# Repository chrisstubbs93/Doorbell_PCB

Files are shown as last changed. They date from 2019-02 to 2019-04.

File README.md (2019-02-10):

# Lecturer Availability Door Announcer

## Abstract
Traditionally a student would have to summon a lecturer in a shared office by knocking on the door. This disturbs the other lecturers in the office, and the desired lecturer may not even be present.

A system to alert a specific lecturer to the presence of someone at the door is not currently widely adopted. To investigate how such a system should work, it is crucial to gain insight into the current solutions to the individual technical challenges.

## Introduction
The main aim of this project is to develop a battery-operated device with inputs to receive interaction from the student, and outputs to feed back to the student and lecturer. It is to be fixed to the inside of the door of a multiple occupied lecturer's room. Through this device anyone outside the door shall be able to raise the attention of a single lecturer, and not to everyone in the room (which is what knocking at the door does). When a student operates the device, a notification should be sent to the appropriate lecturer’s mobile phone. It should also be possible for students to see the status/availability of a lecturer from the device, which the lecturer can set.

## Hardware

 - ESP32-WROOM-32
 - Waveshare 2.9" B/W ePaper
 - TCA9548A i2c multiplexer
 - VCNL4020 IR proximity sensor(s)

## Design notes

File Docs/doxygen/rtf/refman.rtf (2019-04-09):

Lecturer Availability Door Announcer

AUTHOR
Version 1.1
Tue Apr 9 2019

Table of Contents

Table of contents

File Index
File List
Here is a list of all files with brief descriptions:
bitmaps.h pagenum
Config.ino pagenum
Doorbell.ino pagenum
GUI.ino pagenum
Hardware.ino pagenum
Settings.h pagenum
Settings_template.h pagenum
Web.ino pagenum

File Documentation
bitmaps.h File Reference
AAAAAAAAAAAAAAAAAAAAVariables
const unsigned char BmpLSBU [] PROGMEM

Detailed Description
Stores bitmap images for display in program memory

Variable Documentation
const unsigned char BmpLSBU [] PROGMEM
AAAAAAAAABAAAAAAAAABThe LSBU logo stored as an array.
Generated from http://javl.github.io/image2cpp/
Invert colours.
Definition at line 15 of file bitmaps.h.

Config.ino File Reference
AAAAAAAAACAAAAAAAAACFunctions
void initFS ()
bool loadConfig ()
bool saveConfig ()
String rot (String in)

Detailed Description
Handles SPIFFS filesystem, loading of configuration files, saving of configuration files.

Function Documentation
void initFS ()
AAAAAAAAADAAAAAAAAADTry to initialize the filesystem. Format the SPIFFS on error and try again (this is normal for first use).
Definition at line 7 of file Config.ino.
7 {
8 Serial.println("[INFO] Mounting filesystem...");
9 if (!SPIFFS.begin()) {
10 errorMsg("Failed to mount file sys.\nAttempting to format.\nThis is normal for 1st use.\nPlease wait 30 seconds.");
11 SPIFFS.format();
12 if (SPIFFS.begin()) {
13 Serial.println("[INFO] SPIFFS format complete");
14 } else {
15 return;
16 }
17 }
18 delay(10);
19 }
bool loadConfig ()
AAAAAAAAAEAAAAAAAAAETry to load the configuration JSON file contents into their variables.
Definition at line 22 of file Config.ino.
22 {
23 File configFile = SPIFFS.open("/config.json", "r");
24 if (!configFile) {
25 errorMsg("Failed to open config file");
26 settingMode = true;
27 return false;
28 }
29 size_t size = configFile.size();
30 if (size > 1024) {
31 errorMsg("Config file size is too large");
32 settingMode = true;
33 return false;
34 }
35 std::unique_ptr<char[]> buf(new char[size]); // Allocate a buffer to store contents of the file.
36 configFile.readBytes(buf.get(), size); //Mutable buffer
37 StaticJsonBuffer<5000> jsonBuffer;
38 JsonObject& json = jsonBuffer.parseObject(buf.get());
39 if (!json.success()) {
40 errorMsg("Failed to parse cfg file.\nThis is normal for 1st use.");
41 settingMode = true;
42 return false;
43 }
44 //Restore basic device settings
45 EAP_IDENTITY = (const char*)json["EAP_IDENTITY"];
46 EAP_PASSWORD = (const char*)json["EAP_PASSWORD"];
47 ssid = (const char*)json["ssid"];
48 wifipsk = (const char*)json["wifipsk"];
49 www_username = (const char*)json["www_username"];
50 www_password = (const char*)json["www_password"];
51 room = (const char*)json["room"];
52 thres = json["thres"];
53 busyNotif = json["busyNotif"];
54 powerSave = json["powerSave"];
55 sleepDelay = json["sleepDelay"];
56 if (sleepDelay < 1) sleepDelay = 1; //coerce to greater than zero
57
58 //Restore lecturer details
59 for (int i = 0; i < 5; i++) {
60 lecturerNames[i] = (const char*)json["lecturerNames"][(String)i];
61 lecturerIFTTkeys[i] = (const char*)json["lecturerIFTTkeys"][(String)i];
62 lecturerStatus[i] = (const char*)json["lecturerStatus"][(String)i];
63 }
64
65 //Serial.print("[INFO] Parameters loaded:");
66 //json.printTo(Serial);
67 //Serial.println();
68 return true;
69 }
String rot (String in)
AAAAAAAAAFAAAAAAAAAFROT13 encryption algorithm.
Definition at line 115 of file Config.ino.
115 {
116 String out;
117 for (int i = 0; i < in.length(); ++i) {
118 if (isalpha(in[i])) {
119 if (in[i] >= 'a' && in[i] <= 'm') {
120 out += char(in[i] + 13);
121 } else if (in[i] >= 'n' && in[i] <= 'z') {
122 out += char(in[i] - 13);
123 } else if (in[i] >= 'A' && in[i] <= 'M') {
124 out += char(in[i] + 13);
125 } else if (in[i] >= 'N' && in[i] <= 'Z') {
126 out += char(in[i] - 13);
127 }
128 } else {
129 out += char(in[i]);
130 }
131 }
132 return out;
133 }
bool saveConfig ()
AAAAAAAAAGAAAAAAAAAGSave the config variable to the configuration JSON file.
Definition at line 72 of file Config.ino.
72 {
73 StaticJsonBuffer<5000> jsonBuffer;
74 JsonObject& json = jsonBuffer.createObject();
75 //Store basic device settings
76 json["EAP_IDENTITY"] = EAP_IDENTITY;
77 json["EAP_PASSWORD"] = EAP_PASSWORD;
78 json["ssid"] = ssid;
79 json["wifipsk"] = wifipsk;
80 json["www_username"] = www_username;
81 json["www_password"] = www_password;
82 json["room"] = room;
83 json["thres"] = thres;
84 json["busyNotif"] = busyNotif;
85 json["powerSave"] = powerSave;
86 json["sleepDelay"] = sleepDelay;
87
88 //Store lecturer details
89 JsonObject& jsonLecNames = jsonBuffer.createObject();
90 JsonObject& jsonLecKeys = jsonBuffer.createObject();
91 JsonObject& jsonLecStatus = jsonBuffer.createObject();
92 for (int i = 0; i < 5; i++) {
93 jsonLecNames[(String)i] = lecturerNames[i];
94 jsonLecKeys[(String)i] = lecturerIFTTkeys[i];
95 jsonLecStatus[(String)i] = lecturerStatus[i];
96 }
97 json["lecturerNames"] = jsonLecNames;
98 json["lecturerIFTTkeys"] = jsonLecKeys;
99 json["lecturerStatus"] = jsonLecStatus;
100
101 //Serial.print("[INFO] Parameters stored:");
102 //json.printTo(Serial);
103 //Serial.println();
104
105 File configFile = SPIFFS.open("/config.json", "w");
106 if (!configFile) {
107 Serial.println("[ERROR] Failed to open config file for writing");
108 return false;
109 }
110 json.printTo(configFile);
111 return true;
112 }

Doorbell.ino File Reference
AAAAAAAAAHAAAAAAAAAHFunctions
GxIO_Class io (SPI, 15, 4, 5)
Define the hardware pins used by the ePaper display for SPI. 15=CS, 4=DC, 5=RST.

GxEPD_Class display (io, 5, 16)
Define the hardware pins used by the ePaper display for control. 5=RST, 16=BUSY..

WebServer webServer (80)
Web server used for setup wizard and config interface.

void setup ()
void loop ()
Variables
DNSServer dnsServer
DNS server used for captive portal in setup mode.

boolean settingMode
Is the device in setup wizard mode (true) or normal mode (false)?

int doorbells = 0
Number of VCNL4020 sensors detected.

bool sleeping = false
Is the device in or about to enter deep sleep mode for power saving?

Detailed Description
Main file for the Lecturer Availability Door Announcer final year BEng project by Chris Stubbs.

Function Documentation
GxEPD_Class display (io , 5 , 16 )
AAAAAAAAAIAAAAAAAAAI
Define the hardware pins used by the ePaper display for control. 5=RST, 16=BUSY..
GxIO_Class io (SPI , 15 , 4 , 5 )
AAAAAAAAAJAAAAAAAAAJ
Define the hardware pins used by the ePaper display for SPI. 15=CS, 4=DC, 5=RST.
void loop ()
AAAAAAAAAKAAAAAAAAAKLoop function runs continuously. Poll devices and run background tasks.
Definition at line 77 of file Doorbell.ino.
77 {
78 wifiTasks();
79 scanVCNLs();
80 checkButtons();
81 manageSleep();
82 delay(SCAN_INTERVAL);
83 }
void setup ()
AAAAAAAAALAAAAAAAAALSetup function runs once on startup. Detect boot mode (normal or waking up from deep sleep). Perform setup.
Definition at line 36 of file Doorbell.ino.
36 {
37 Wire.begin();
38 Serial.begin(115200);
39 Serial.println((String)"[INFO] Lecturer availability door announcer version " + (String)VERSION);
40 wakeup_reason();
41 display.init();
42 initGPIO();
43 if (bootmode() == 6) displayVersion();
44 initFS();
45 bool configstatus = loadConfig();
46 if (bootmode() == 3) { //wakeup cause by timer. Update battery % on screen and go back to sleep.
47 sleeping = true; //set the sleeping flag
48 writeNames(); //show the sleeping flag on screen
49 entersleep(); //go to sleep
50 }
51 if (configstatus) {
52 //Config loaded OK. Try to connect to WiFi.
53 if (connectWiFi()) {
54 //WiFi connected OK. Start config web server and continue boot.
55 startWebServer();
56 } else {
57 //WiFi failed to connect. Start setup mode and abort boot.
58 setupMode();
59 return;
60 }
61 }
62 else {
63 setupMode();
64 return; //abort boot to carry out initial setup wizard
65 }
66 detectVCNLs();
67 if (bootmode() == 1) {
68 int source = interruptSource();
69 Serial.println((String)"[INFO] Interrupt triggered by sensor " + interruptSource());
70 ring(source);
71 }
72 calibrateVCNLs();
73 writeNames();
74 }
WebServer webServer (80 )
AAAAAAAAAMAAAAAAAAAM
Web server used for setup wizard and config interface.

Variable Documentation
DNSServer dnsServer
AAAAAAAAANAAAAAAAAAN
DNS server used for captive portal in setup mode.
Definition at line 29 of file Doorbell.ino.
int doorbells = 0
AAAAAAAAAOAAAAAAAAAO
Number of VCNL4020 sensors detected.
Definition at line 32 of file Doorbell.ino.
boolean settingMode
AAAAAAAAAPAAAAAAAAAP
Is the device in setup wizard mode (true) or normal mode (false)?
Definition at line 31 of file Doorbell.ino.
bool sleeping = false
AAAAAAAAAQAAAAAAAAAQ
Is the device in or about to enter deep sleep mode for power saving?
Definition at line 33 of file Doorbell.ino.

GUI.ino File Reference
AAAAAAAAARAAAAAAAAARFunctions
void displayVersion ()
void errorMsg (String ermsg)
void setupMsg (String apSSID)
void writeNames ()
void addToLog (const String n)
void displayLog ()
void clearLog ()
void showInfo ()
String wordWrap (String in)
Variables
String logbuffer [8] = { "", "", "", "", "", "", "", "" }
Buffer of last 8 log messages to show on screen. FIFO queue.

const GFXfont * font = &FreeMonoBold9pt7b
Define the font used for the GUI.

Detailed Description
Handles drawing of GUI elements on ePaper display

Function Documentation
void addToLog (const String n)
AAAAAAAAASAAAAAAAAASShuffle the log buffer and add a new time. Display log.
Definition at line 115 of file GUI.ino.
116 {
117 for (int i = 0; i < 7; i++) {
118 logbuffer[i] = logbuffer[i + 1];
119 }
120 logbuffer[7] = n;
121 displayLog();
122 }
void clearLog ()
AAAAAAAAATAAAAAAAAATRemove all entries in the log buffer.
Definition at line 139 of file GUI.ino.
140 {
141 for (int i = 0; i <= 7; i++) {
142 logbuffer[i] = "";
143 }
144 }
void displayLog ()
AAAAAAAAAUAAAAAAAAAUDisplay all log items in the buffer, most recent at the bottom.
Definition at line 125 of file GUI.ino.
126 {
127 display.setRotation(1);
128 display.fillScreen(GxEPD_WHITE);
129 display.setTextColor(GxEPD_BLACK);
130 display.setFont(font);
131 display.setCursor(0, 0);
132 for (int i = 0; i < 8; i++) {
133 display.println(logbuffer[i]);
134 }
135 display.update();
136 }
void displayVersion ()
AAAAAAAAAVAAAAAAAAAVDisplays an LSBU splashscreen followed by a description/version no. splashscreen.
Definition at line 11 of file GUI.ino.
12 {
13 //set up parameters
14 display.setRotation(1);
15 display.fillScreen(GxEPD_WHITE);
16 display.setTextColor(GxEPD_BLACK);
17 display.setFont(font);
18 //show LSBU logo
19 display.drawBitmap(0, 0, BmpLSBU, 296, 128, GxEPD_BLACK);
20 display.update();
21 delay(2000);
22 //Show version
23 display.fillScreen(GxEPD_WHITE);
24 display.setCursor(0, 0);
25 display.println();
26 display.println("Lecturer availability door");
27 display.println("announcer");
28 display.println();
29 display.println("Final year BEng project");
30 display.println("By Chris Stubbs 2018/19");
31 display.println((String)"FW Revision: " + (String)VERSION);
32 display.println("Starting up...");
33 display.update();
34 delay(3000);
35 }
void errorMsg (String ermsg)
AAAAAAAAAWAAAAAAAAAWDisplays a full screen error message with title and content for 5 seconds. Can be dismissed by pressing either button. Message is also printed to the serial port and the ERROR LED flashed.
Definition at line 38 of file GUI.ino.
39 {
40 digitalWrite(LEDERRPIN, HIGH);
41 String tmpermsg = ermsg;
42 tmpermsg.replace("\n", " ");
43 Serial.println("[ERROR] " + tmpermsg);
44 display.setRotation(1);
45 display.fillScreen(GxEPD_WHITE);
46 display.setTextColor(GxEPD_BLACK);
47 display.setFont(font);
48 display.setCursor(0, 0);
49 display.println();
50 display.println("!!!----!!! Error !!!----!!!");
51 display.println(ermsg);
52 display.update();
53 unsigned long tmr = millis();
54 while ((millis() - tmr < 5000)) {
55 if (digitalRead(BTNAPIN)) break; //allow button press to dismiss error
56 if (digitalRead(BTNBPIN)) break;
57 }
58 digitalWrite(LEDERRPIN, LOW);
59 }
void setupMsg (String apSSID)
AAAAAAAAAXAAAAAAAAAXInstructs user to connect to access point and run setup wizard.
Definition at line 62 of file GUI.ino.
63 {
64 Serial.println((String)"[INFO] Starting config access point named " + apSSID);
65 Serial.println((String)"[INFO] Starting config web server at " + WiFi.softAPIP().toString());
66 display.setRotation(1);
67 display.fillScreen(GxEPD_WHITE);
68 display.setTextColor(GxEPD_BLACK);
69 display.setFont(font);
70 display.setCursor(0, 14);
71 display.println("------- Config Mode -------");
72 display.println("Scan for access points");
73 display.println("and connect to " + apSSID + ".");
74 display.println();
75 display.println("Go to " + WiFi.softAPIP().toString());
76 display.println("to set up.");
77 display.update();
78 }
void showInfo ()
AAAAAAAAAYAAAAAAAAAYShows simple menu with FW version, IP, n sensors found. Also allows user to initiate a reset of the device configuration.
Definition at line 147 of file GUI.ino.
147 {
148 //set up parameters
149 bool shown = false;
150 while (!shown) {
151 display.setRotation(1);
152 display.fillScreen(GxEPD_WHITE);
153 display.setTextColor(GxEPD_BLACK);
154 display.setFont(font);
155 display.fillScreen(GxEPD_WHITE);
156 display.setCursor(0, 14);
157 display.println((String)"FW Revision: " + (String)VERSION);
158 display.println("IP addr: " + WiFi.localIP().toString());
159 display.println("Connected to " + ssid);
160 display.println((String)doorbells + " sensors found");
161 display.println();
162 display.println();
163 display.println("[A]-Close [B]-Reset");
164 display.update();
165 shown = true;
166 while (digitalRead(BTNAPIN)) {}
167 unsigned long tmr = millis();
168 while ((millis() - tmr < 60000)) {
169 wifiTasks();//Run WiFi background tasks while waiting
170 if (digitalRead(BTNAPIN)) break;
171 if (digitalRead(BTNBPIN)) {
172 while (digitalRead(BTNBPIN)) {}
173 display.fillScreen(GxEPD_WHITE);
174 Serial.println("Are you sure you want to\nreset this device?");
175 display.setCursor(0, 14);
176 display.println("Are you sure you want to");
177 display.println("reset this device?");
178 display.println();
179 display.println("All settings will be lost.");
180 display.println();
181 display.println("[A]-No");
182 display.println("[B]-Yes (hold for 5 sec)");
183 display.update();
184 if (digitalRead(BTNAPIN)) break;
185 while (1) {
186 if (digitalRead(BTNAPIN)) {
187 shown = false;
188 break;
189 }
190 if (digitalRead(BTNBPIN)) {
191 unsigned long tmr2 = millis();
192 while (digitalRead(BTNBPIN)) {
193 if ((millis() - tmr2 > 5000)) {
194 //Clear settings and restart
195 SPIFFS.remove("/config.json");
196 delay(1000);
197 ESP.restart();
198 }
199 }
200 }
201 }
202 }
203 }
204 }
205 writeNames();
206 }
String wordWrap (String in)
AAAAAAAAAZAAAAAAAAAZWrap words around spaces to print nicely on screen.
Definition at line 209 of file GUI.ino.
209 {
210 if (in.length() > 27) {
211 for (int i = 27; i > 1; i--) { //work backwards from limit of string to first space
212 if (in.charAt(i) == ' ') {
213 return (in.substring(0, i) + "\n" + in.substring(i + 1, in.length())); //there is a space to replace with a line break
214 }
215 }
216 return in; //There were no spaces to replace, return plain string
217 } else {
218 return in; //String will fit on screen, return plain string
219 }
220 }
void writeNames ()
AAAAAAAABAAAAAAAAABAWrite the room name, all lecturer names, status, battery percentage and sleep status to the display.
Definition at line 81 of file GUI.ino.
82 {
83 display.setRotation(1);
84 display.fillScreen(GxEPD_WHITE);
85 display.setTextColor(GxEPD_BLACK);
86 display.setFont(font);
87 display.setCursor(0, 14);
88 display.println("-------- Room " + room + " --------");
89 for (int i = 0; i < 5; i++) {
90 display.setCursor(0, 35 + (16 * i));
91 display.println(lecturerNames[i]);
92 display.setCursor(175, 35 + (16 * i));
93 if (lecturerNames[i] != "") display.println("-");
94 display.setCursor(190, 35 + (16 * i));
95 display.println(lecturerStatus[i]);
96 }
97 display.setCursor(270, 122);
98 if (sleeping) display.println("Zz");
99
100 //Draw battery icon and percentage
101 float VBAT = ((200.0f / 100.0f) * 3.30f * float(analogRead(BATTMONPIN)) / 4095.0f) + 0.2f; // LiPo battery
102 int vbatt = (float)((100.0f / 4.2f) * VBAT);
103 Serial.print("[INFO] Battery Voltage = "); Serial.print(VBAT, 2); Serial.println(" V");
104 display.drawRect(1, 113, 30, 13, GxEPD_BLACK);
105 display.drawRect(2, 114, 28, 11, GxEPD_BLACK);
106 display.fillRect(31, 116, 3, 7, GxEPD_BLACK);
107 display.fillRect(1, 113, (int)(vbatt / 3.33), 13, GxEPD_BLACK); //fill to battery %
108 display.setCursor(35, 123);
109 display.println((String)vbatt + "%");
110
111 display.update(); //Send buffer to display
112 }

Variable Documentation
const GFXfont* font = &FreeMonoBold9pt7b
AAAAAAAABBAAAAAAAABB
Define the font used for the GUI.
Definition at line 8 of file GUI.ino.
String logbuffer[8] = { "", "", "", "", "", "", "", "" }
AAAAAAAABCAAAAAAAABC
Buffer of last 8 log messages to show on screen. FIFO queue.
Definition at line 7 of file GUI.ino.

Hardware.ino File Reference
AAAAAAAABDAAAAAAAABDFunctions
void initGPIO ()
void setVCOM (unsigned char d)
void tcaselect (uint8_t i)
int tcaget ()
void detectVCNLs ()
void calibrateVCNLs ()
void checkButtons ()
void manageSleep ()
void entersleep ()
void wakeup_reason ()
int bootmode ()
void scanVCNLs ()
void setupVCNLinterrupt ()
uint16_t getBackgroundProximity ()
int interruptSource ()
Variables
long average [] = {0, 0, 0, 0, 0, 0, 0, 0}
Array of average reading of all sensors.

long threshold [] = {0, 0, 0, 0, 0, 0, 0, 0}
Array of threshold limits to trigger each sensor.

long reading [] = {0, 0, 0, 0, 0, 0, 0, 0}
Current reading of each sensor.

Adafruit_VCNL4010 vcnl
Object for the VNCL sensor.

unsigned long lastPressed = 0
Time in ms since boot that a sensor was last pressed. Used to determine when to enter sleep mode after inactivity.

Detailed Description
Handles I2C multiplexer, connection to VCNL IR proximity sensors, proximity sensor related functions, initialisation of GPIO, scanning of buttons.

Function Documentation
int bootmode ()
AAAAAAAABEAAAAAAAABEDetermine type of boot mode. 1 = sensor interrupt, 2 = button interrupt, 3 = periodic timer wakeup, 6 = normal startup.
Definition at line 168 of file Hardware.ino.
168 {
169 esp_sleep_wakeup_cause_t wakeup_reason;
170 wakeup_reason = esp_sleep_get_wakeup_cause();
171 if (wakeup_reason > 5 or wakeup_reason < 1){
172 return 6;
173 } else {
174 return wakeup_reason;
175 }
176 }
void calibrateVCNLs ()
AAAAAAAABFAAAAAAAABFCalibrate VCNL threshold by averaging N_THRES_SAMPLES samples and multiplying by thres
Definition at line 94 of file Hardware.ino.
94 {
95 for (int bus = 0; bus < doorbells; bus++) {
96 tcaselect(bus);
97 Serial.print("[INFO] Calibrating proximity threshold on bus " + (String)bus + " ");
98 vcnl.setLEDcurrent(LEDCURR); //Set IR LED on to take measurement
99 delay(10); //small delay to allow IR LED to stabilise
100 for (int i = 0; i <= N_THRES_SAMPLES; i++) {
101 int tmp = vcnl.readProximity();
102 average[bus] = average[bus] + tmp;
103 Serial.print((String)((100 / N_THRES_SAMPLES)*i) + "% ");
104 delay(100);
105 }
106 vcnl.setLEDcurrent(0); //Set IR LED off
107 average[bus] = average[bus] / N_THRES_SAMPLES;
108 threshold[bus] = average[bus] * thres;
109 Serial.println((String)"Average level was: " + average[bus] + " Threshold set to: " + threshold[bus]);
110 }
111 Serial.println("[INFO] Calibration done");
112 }
void checkButtons ()
AAAAAAAABGAAAAAAAABGCheck if hardware buttons are pressed and run actions.
Definition at line 115 of file Hardware.ino.
115 {
116 if (digitalRead(BTNAPIN)) {
117 lastPressed = millis(); //record the button was pressed for sleep mode
118 Serial.println("[INFO] Button A Pressed");
119 showInfo();
120 while (digitalRead(BTNAPIN)) {}
121 }
122 if (digitalRead(BTNBPIN)) {
123 lastPressed = millis(); //record the button was pressed for sleep mode
124 Serial.println("[INFO] Button B Pressed");
125 while (digitalRead(BTNBPIN)) {}
126 }
127 }
void detectVCNLs ()
AAAAAAAABHAAAAAAAABHAttempt to initialise connected VCNL's one by one
Definition at line 64 of file Hardware.ino.
64 {
65 Serial.println("[INFO] Autodetecting sensors....");
66 //addToLog("Autodetecting sensors....");
67 for (int bus = 0; bus <= 7; bus++) {
68 tcaselect(bus);
69 int trynum = 1;
70 while (! vcnl.begin() && trynum < TRIES) {
71 if (DEBUG_READINGS == 1) Serial.println((String)"[DEBUG] Try " + trynum);
72 trynum++;
73 delay(100);
74 }
75 if (trynum < TRIES) {
76 //found
77 Serial.println((String)"[INFO] Found VCNL40xx on bus " + bus);
78 doorbells++;
79 }
80 else {
81 //not found
82 Serial.println((String)"[INFO] No VCNL40xx on bus " + (String)bus + " terminating autodetection.");
83 break;
84 }
85 }
86 Serial.println("[INFO] Number of doorbells found: " + (String)doorbells);
87 //addToLog((String)doorbells + " sensors found.");
88 if (doorbells == 0) {
89 errorMsg("Hardware error.\nNo VCNL sesnors found.\nContact support.");
90 }
91 }
void entersleep ()
AAAAAAAABIAAAAAAAABISet up interrupts to wake device, then go to deep sleep for power saving.
Definition at line 143 of file Hardware.ino.
143 {
144 Serial.println("[INFO] Entering sleep mode");
145 esp_sleep_enable_ext0_wakeup(GPIO_NUM_32, 0); //interrupt on VCNL sum
146 esp_sleep_enable_ext1_wakeup(INTERRUPTPINMASK, ESP_EXT1_WAKEUP_ANY_HIGH); //interrupt on A/B buttons
147 esp_sleep_enable_timer_wakeup(1800 * 1000000); //interrupt every hour to update battery etc
148 delay(500); //delay to finish setup before CPU halted
149 esp_deep_sleep_start();
150 }
uint16_t getBackgroundProximity ()
AAAAAAAABJAAAAAAAABJTake a proximity reading without disturbing the interrupt setup.
Definition at line 235 of file Hardware.ino.
235 {
236 vcnl.setLEDcurrent(LEDCURR); //Set IR LED on to take measurement
237 delay(10); //small delay to allow IR LED to stabilise
238 vcnl.write8(0x80, 0x03); //run continuous measurements
239 uint16_t p = vcnl.read8(0x87);
240 p = p << 8;
241 p = p + vcnl.read8(0x88);
242 return p;
243 }
void initGPIO ()
AAAAAAAABKAAAAAAAABKInitialise the GPIO pins. This should be run AFTER initialising the display so the MISO pin can be detached from the pin matrix and reused.
Definition at line 17 of file Hardware.ino.
17 {
18 pinMode(BTNAPIN, INPUT);
19 pinMode(BTNBPIN, INPUT);
20 pinMode(INTERRUPTPIN, INPUT);
21 pinMode(BATTMONPIN, INPUT);
22
23 pinMatrixInDetach(VSPIQ_OUT_IDX, false, false); //detatch pin 19 from the VSPI MISO.
24 pinMode(LEDAVAILPIN, OUTPUT);
25 pinMode(LEDBUSYPIN, OUTPUT);
26 pinMode(LEDOKPIN, OUTPUT);
27 pinMode(LEDERRPIN, OUTPUT);
28 }
int interruptSource ()
AAAAAAAABLAAAAAAAABLDetermine which sensor caused a hardware interrupt.
Definition at line 246 of file Hardware.ino.
246 {
247 for (int bus = 0; bus < doorbells; bus++) {
248 tcaselect(bus);
249 //Serial.print((String)"Device " + bus + " has an interrupt register with contents "); Serial.println(vcnl.read8(0x8E),HEX);
250 if (vcnl.read8(0x8E) & 0x01) { //check interrupt register on VCNL
251 return bus;
252 }
253 }
254 return 0;
255 }
void manageSleep ()
AAAAAAAABMAAAAAAAABMDetermine if device should enter deep sleep for power saving.
Definition at line 130 of file Hardware.ino.
130 {
131 if (powerSave) {
132 if (millis() - lastPressed > sleepDelay * 60000) {
133 //go to sleep if no activity for x mins
134 setupVCNLinterrupt(); //set up the VCNLs for interrupt
135 sleeping = true; //set the sleeping flag
136 writeNames(); //show the sleeping flag on screen
137 entersleep(); //go to sleep
138 }
139 }
140 }
void scanVCNLs ()
AAAAAAAABNAAAAAAAABNTake reading from each sensor. Notify lecturer if above threshold.
Definition at line 179 of file Hardware.ino.
179 {
180 if (settingMode) return;
181 for (int bus = 0; bus < doorbells; bus++) {
182 tcaselect(bus);
183 vcnl.setLEDcurrent(LEDCURR); //Set IR LED on to take measurement
184 delay(10); //small delay to allow IR LED to stabilise
185 reading[bus] = vcnl.readProximity();
186 if (reading[bus] > threshold[bus]) {
187 Serial.println((String)"[INFO] Doorbell pressed on bus " + bus + " reading:" + reading[bus]);
188 ring(bus);
189 while (reading[bus] > threshold[bus])
190 {
191 reading[bus] = vcnl.readProximity();
192 delay(SCAN_INTERVAL);
193 }
194 }
195 //Set LED off to save power
196 vcnl.setLEDcurrent(0);
197 }
198 if (DEBUG_READINGS == 1) {
199 Serial.print("[DEBUG] Current readings:,");
200 for (int i = 0; i <= 7; i++) {
201 char buf[50];
202 sprintf(buf, "%05d,", reading[i]);
203 Serial.print(buf);
204 }
205 Serial.print("[DEBUG] Thresholds: ,");
206 for (int i = 0; i <= 7; i++) {
207 char buf[50];
208 sprintf(buf, "%05d,", threshold[i]);
209 Serial.print(buf);
210 }
211 }
212 }
void setupVCNLinterrupt ()
AAAAAAAABOAAAAAAAABOSet up interrupt on each device when threshold exceeded. (allows detection of touch interaction when CPU asleep).
Definition at line 215 of file Hardware.ino.
215 {
216 //once the interrupt is set up, the proximity must only be read using background measurement
217 for (int bus = 0; bus < doorbells; bus++) {
218 tcaselect(bus);
219 Serial.println("[INFO] Setting interrupt on bus " + (String)bus + " ");
220 vcnl.setLEDcurrent(LEDCURR); //Set IR LED on to take measurement
221 delay(10); //small delay to allow IR LED to stabilise
222 vcnl.write8(0x89, 0x02); //set up interrupt type
223 //set low thres to 0
224 vcnl.write8(0x8A, 0x00);
225 vcnl.write8(0x8B, 0x00);
226 //set high thres to value from array
227 vcnl.write8(0x8C, highByte(threshold[bus]));
228 vcnl.write8(0x8D, lowByte(threshold[bus]));
229 //run continuous measurements
230 vcnl.write8(0x80, 0x03);
231 }
232 }
void setVCOM (unsigned char d)
AAAAAAAABPAAAAAAAABPSet the VCOM. This isn't normally needed unless the ePaper is particularly bad.
Definition at line 31 of file Hardware.ino.
31 {
32 digitalWrite(4, LOW);
33 digitalWrite(15, LOW);
34 SPI.transfer(0x2C); //Write VCOM register
35 digitalWrite(15, HIGH);
36 digitalWrite(4, HIGH);
37 digitalWrite(15, LOW);
38 SPI.transfer(d);
39 digitalWrite(15, HIGH);
40 }
int tcaget ()
AAAAAAAABQAAAAAAAABQCheck the current i2c sub-bus for a specific sensor. Output 0...7
Definition at line 54 of file Hardware.ino.
54 {
55 Wire.requestFrom(TCAADDR, 1);
56 byte c = Wire.read();
57 for (int i = 0; i <= 7; i++) {
58 if (c == 0x01) return i;
59 c = c >> 1;
60 }
61 }
void tcaselect (uint8_t i)
AAAAAAAABRAAAAAAAABRSelects which i2c sub-bus on the mux for a specific sensor to connect to and checks it, retrying if it's not correct. (input 0...7)
Definition at line 43 of file Hardware.ino.
43 {
44 if (i > 7) return;
45 do {
46 if (DEBUG_READINGS == 1) Serial.println((String)"[DEBUG] Selecting bus " + i);
47 Wire.beginTransmission(TCAADDR);
48 Wire.write(1 << i);
49 Wire.endTransmission();
50 } while (!(tcaget() == i));
51 }
void wakeup_reason ()
AAAAAAAABSAAAAAAAABSPrint the reason for wakeup to the serial port.
Definition at line 153 of file Hardware.ino.
153 {
154 esp_sleep_wakeup_cause_t wakeup_reason;
155 wakeup_reason = esp_sleep_get_wakeup_cause();
156 switch (wakeup_reason)
157 {
158 case 1 : Serial.println("[INFO] Wakeup caused by external signal using RTC_IO"); break; //EXT0 - VCNL
159 case 2 : Serial.println("[INFO] Wakeup caused by external signal using RTC_CNTL"); break; //EXT1 - A/B
160 case 3 : Serial.println("[INFO] Wakeup caused by timer"); break;
161 case 4 : Serial.println("[INFO] Wakeup caused by touchpad"); break;
162 case 5 : Serial.println("[INFO] Wakeup caused by ULP program"); break;
163 default : Serial.println("[INFO] Wakeup was not caused by deep sleep"); break;
164 }
165 }

Variable Documentation
long average[] = {0, 0, 0, 0, 0, 0, 0, 0}
AAAAAAAABTAAAAAAAABT
Array of average reading of all sensors.
Definition at line 7 of file Hardware.ino.
unsigned long lastPressed = 0
AAAAAAAABUAAAAAAAABU
Time in ms since boot that a sensor was last pressed. Used to determine when to enter sleep mode after inactivity.
Definition at line 14 of file Hardware.ino.
long reading[] = {0, 0, 0, 0, 0, 0, 0, 0}
AAAAAAAABVAAAAAAAABV
Current reading of each sensor.
Definition at line 9 of file Hardware.ino.
long threshold[] = {0, 0, 0, 0, 0, 0, 0, 0}
AAAAAAAABWAAAAAAAABW
Array of threshold limits to trigger each sensor.
Definition at line 8 of file Hardware.ino.
Adafruit_VCNL4010 vcnl
AAAAAAAABXAAAAAAAABX
Object for the VNCL sensor.
Definition at line 11 of file Hardware.ino.

Settings.h File Reference
AAAAAAAABYAAAAAAAABYVariables
String ssid = ""
String wifipsk = ""
String EAP_IDENTITY = ""
String EAP_PASSWORD = ""
String www_username = "admin"
String www_password = "esp32"
String room = "T815"
String lecturerNames [5] = { "Chris Stubbs", "Oswaldo Cadenas", "Fang Duan", "Jeremy Ball", ""}
String lecturerIFTTkeys [5] = { "cWn7UxwOXLX-pqSYsF82Ge", "REMOVEcMalAefCTKzVtoXHlMz9Wk", "", "", ""}
String lecturerStatus [5] = { "Available", "Away", "Busy", "Busy", ""}
float thres = 2
bool busyNotif = false
bool powerSave = false
int sleepDelay = 1

Detailed Description
Contains user settings and presets that can be changed for build

Variable Documentation
bool busyNotif = false
AAAAAAAABZAAAAAAAABZ
Definition at line 20 of file Settings.h.
String EAP_IDENTITY = ""
AAAAAAAACAAAAAAAAACA
Definition at line 9 of file Settings.h.
String EAP_PASSWORD = ""
AAAAAAAACBAAAAAAAACB
Definition at line 10 of file Settings.h.
String lecturerIFTTkeys[5] = { "cWn7UxwOXLX-pqSYsF82Ge", "REMOVEcMalAefCTKzVtoXHlMz9Wk", "", "", ""}
AAAAAAAACCAAAAAAAACC
Definition at line 17 of file Settings.h.
String lecturerNames[5] = { "Chris Stubbs", "Oswaldo Cadenas", "Fang Duan", "Jeremy Ball", ""}
AAAAAAAACDAAAAAAAACD
Definition at line 16 of file Settings.h.
String lecturerStatus[5] = { "Available", "Away", "Busy", "Busy", ""}
AAAAAAAACEAAAAAAAACE
Definition at line 18 of file Settings.h.
bool powerSave = false
AAAAAAAACFAAAAAAAACF
Definition at line 21 of file Settings.h.
String room = "T815"
AAAAAAAACGAAAAAAAACG
Definition at line 15 of file Settings.h.
int sleepDelay = 1
AAAAAAAACHAAAAAAAACH
Definition at line 22 of file Settings.h.
String ssid = ""
AAAAAAAACIAAAAAAAACI
Definition at line 7 of file Settings.h.
float thres = 2
AAAAAAAACJAAAAAAAACJ
Definition at line 19 of file Settings.h.
String wifipsk = ""
AAAAAAAACKAAAAAAAACK
Definition at line 8 of file Settings.h.
String www_password = "esp32"
AAAAAAAACLAAAAAAAACL
Definition at line 12 of file Settings.h.
String www_username = "admin"
AAAAAAAACMAAAAAAAACM
Definition at line 11 of file Settings.h.

Settings_template.h File Reference
AAAAAAAACNAAAAAAAACNVariables
String ssid = ""
WiFi SSID the device will connect to. Set from setup wizard.

String wifipsk = ""
WiFi pre-shared key (password) the device will connect with. Set from setup wizard.

String EAP_IDENTITY = ""
WPA2-ENTERPRISE (eduroam) email address. Set from setup wizard.

String EAP_PASSWORD = ""
WPA2-ENTERPRISE (eduroam) password. Set from setup wizard.

String www_username = "admin"
Defualt username for web config interface. Set from web config interface.

String www_password = "esp32"
Defualt password for web config interface. Set from web config interface.

String room = "T815"
Name of room device is fixed to. Set from web config interface.

String lecturerNames [5] = { "Name1", "Name2", "Name3", "", ""}
Array of lectureres names. Set from web config interface.

String lecturerIFTTkeys [5] = { "Key1", "Key2", "Key3", "", ""}
Array of lecturer IFTTT keys. Set from web config interface.

String lecturerStatus [5] = { "Available", "Away", "Busy", "", ""}
Array of lecturer status. Set from web config interface.

float thres = 2
Threshold for sensor.

bool busyNotif = false
Notify lecturer anyway if they are busy?

bool powerSave = false
Enter power saving mode after inactivity?

int sleepDelay = 15
Period of inactivity in mins before entering power save mode.

Detailed Description
Contains user settings and presets that can be changed for build. Rename this file to Settings.h.

Variable Documentation
bool busyNotif = false
AAAAAAAACOAAAAAAAACO
Notify lecturer anyway if they are busy?
Definition at line 20 of file Settings_template.h.
String EAP_IDENTITY = ""
AAAAAAAACPAAAAAAAACP
WPA2-ENTERPRISE (eduroam) email address. Set from setup wizard.
Definition at line 9 of file Settings_template.h.
String EAP_PASSWORD = ""
AAAAAAAACQAAAAAAAACQ
WPA2-ENTERPRISE (eduroam) password. Set from setup wizard.
Definition at line 10 of file Settings_template.h.
String lecturerIFTTkeys[5] = { "Key1", "Key2", "Key3", "", ""}
AAAAAAAACRAAAAAAAACR
Array of lecturer IFTTT keys. Set from web config interface.
Definition at line 17 of file Settings_template.h.
String lecturerNames[5] = { "Name1", "Name2", "Name3", "", ""}
AAAAAAAACSAAAAAAAACS
Array of lectureres names. Set from web config interface.
Definition at line 16 of file Settings_template.h.
String lecturerStatus[5] = { "Available", "Away", "Busy", "", ""}
AAAAAAAACTAAAAAAAACT
Array of lecturer status. Set from web config interface.
Definition at line 18 of file Settings_template.h.
bool powerSave = false
AAAAAAAACUAAAAAAAACU
Enter power saving mode after inactivity?
Definition at line 21 of file Settings_template.h.
String room = "T815"
AAAAAAAACVAAAAAAAACV
Name of room device is fixed to. Set from web config interface.
Definition at line 15 of file Settings_template.h.
int sleepDelay = 15
AAAAAAAACWAAAAAAAACW
Period of inactivity in mins before entering power save mode.
Definition at line 22 of file Settings_template.h.
String ssid = ""
AAAAAAAACXAAAAAAAACX
WiFi SSID the device will connect to. Set from setup wizard.
Definition at line 7 of file Settings_template.h.
float thres = 2
AAAAAAAACYAAAAAAAACY
Threshold for sensor.
Definition at line 19 of file Settings_template.h.
String wifipsk = ""
AAAAAAAACZAAAAAAAACZ
WiFi pre-shared key (password) the device will connect with. Set from setup wizard.
Definition at line 8 of file Settings_template.h.
String www_password = "esp32"
AAAAAAAADAAAAAAAAADA
Defualt password for web config interface. Set from web config interface.
Definition at line 12 of file Settings_template.h.
String www_username = "admin"
AAAAAAAADBAAAAAAAADB
Defualt username for web config interface. Set from web config interface.
Definition at line 11 of file Settings_template.h.

Web.ino File Reference
AAAAAAAADCAAAAAAAADCFunctions
const IPAddress apIP (192, 168, 1, 1)
Fixed IP address of device for setup wizard in AP mode.

void wifiTasks ()
void ring (const int bus)
boolean connectWiFi ()
boolean checkConnection ()
void startWebServer ()
void setupMode ()
String makePage (String title, String contents)
String urlDecode (String input)
void handleRoot ()
String generateStatusDropdown (uint8_t n)
void saveSettings ()
void handleNotFound ()
void handleReset ()
void handleSetupRoot ()
void handleSettings ()
void handleEduroam ()
void handleSetAP ()
Variables
const char * apSSID = "_SETUP"
Name of SSID for setup wizard access point.

String ssidList
List of all detected SSIDs from scan.

Detailed Description
Handles WiFi access point, WiFi client, DNS server, webservers for initial setup wizard and configuration, IFTTT integration. Also contains all HTML for webservers

Function Documentation
const IPAddress apIP (192 , 168 , 1 , 1 )
AAAAAAAADDAAAAAAAADD
Fixed IP address of device for setup wizard in AP mode.
boolean checkConnection ()
AAAAAAAADEAAAAAAAADECheck WiFi is connected.
Definition at line 158 of file Web.ino.
158 {
159 int count = 0;
160 while ( count < 15 ) {
161 if (WiFi.status() == WL_CONNECTED) {
162 Serial.println("\n[INFO] Connected!");
163 settingMode = false;
164 return (true);
165 }
166 delay(500);
167 Serial.print(".");
168 count++;
169 }
170 Serial.println();
171 return false;
172 }
boolean connectWiFi ()
AAAAAAAADFAAAAAAAADFAttempt to connect to specified WiFi SSID. After 3 failures, default to setup wizard.
Definition at line 103 of file Web.ino.
103 {
104 int connAttempts = 0;
105 while (connAttempts < 3) {
106 connAttempts++;
107 if (EAP_IDENTITY == "") {
108 //if wpa2-psk is configured
109 Serial.println((String)"[INFO] WPA2-PSK mode.");
110 WiFi.begin(ssid.c_str(), rot(wifipsk).c_str());
111 } else {
112 //if eduroam is configured
113 Serial.println((String)"[INFO] WPA2-Enterprise mode.");
114 WiFi.disconnect(true);
115 WiFi.mode(WIFI_STA);
116 const unsigned char* EAP_IDENTITY_A = reinterpret_cast<const unsigned char *>( rot(EAP_IDENTITY).c_str() ); //convert strings to unsigned char for enterprise functions
117 const unsigned char* EAP_PASSWORD_A = reinterpret_cast<const unsigned char *>( rot(EAP_PASSWORD).c_str() );
118 esp_wifi_sta_wpa2_ent_set_username(EAP_IDENTITY_A, strlen(rot(EAP_IDENTITY).c_str())); //set enterprise wifi parameters
119 esp_wifi_sta_wpa2_ent_set_password(EAP_PASSWORD_A, strlen(rot(EAP_PASSWORD).c_str()));
120 esp_wpa2_config_t config = WPA2_CONFIG_INIT_DEFAULT(); //set config settings to default
121 esp_wifi_sta_wpa2_ent_enable(&config); //enable enterprise mode
122 WiFi.begin(ssid.c_str(), rot(wifipsk).c_str()); //connect to AP
123 }
124 Serial.print("[INFO] Connecting to " + ssid + ". Attempt " + connAttempts);
125 addToLog(ssid + " connecting");
126 if (checkConnection()) {
127 return true; //Connected OK.
128 } else {
129 //Connection failed. Try again.
130 if (connAttempts == 3) {
131 //Display last attempt error
132 errorMsg("WiFi connection timed out.\nThis is attempt " + (String)connAttempts + "/3.\nAborting connection.\nEntering setup mode.");
133 } else {
134 //Display retry error
135 errorMsg("WiFi connection timed out.\nThis is attempt " + (String)connAttempts + "/3.\nTrying again in 10s.\nPress [A] to retry now.\nPress [B] to run setup.");
136 unsigned long tmr = millis();
137 while ((millis() - tmr < 10000)) {
138 if (digitalRead(BTNAPIN)) {
139 //User requested retry
140 if (connAttempts == 3) connAttempts = 2; //Manually allow one more try if on last try.
141 break;
142 }
143 if (digitalRead(BTNBPIN)) {
144 //User requested setup mode
145 settingMode = true;
146 return false;
147 }
148 }
149 }
150 settingMode = true;
151 }
152 }
153 //Failed to connect after 3 attempts.
154 return false;
155 }
String generateStatusDropdown (uint8_t n)
AAAAAAAADGAAAAAAAADGGenerate HTML for dropdown with status options.
Definition at line 359 of file Web.ino.
359 {
360 //Generates the HTML string for a status dropdown of the given lecturer number (n).
361 int num = n + 1;
362 String tmphtml = "";
363 tmphtml = "<select name='l" + (String)num + "status'>";
364
365 tmphtml += "<option ";
366 if (lecturerStatus[n] == "Available") tmphtml += "selected ";
367 tmphtml += "value='Available'>Available</option>";
368
369 tmphtml += "<option ";
370 if (lecturerStatus[n] == "Away") tmphtml += "selected ";
371 tmphtml += "value='Away'>Away</option>";
372
373 tmphtml += "<option ";
374 if (lecturerStatus[n] == "Busy") tmphtml += "selected ";
375 tmphtml += "value='Busy'>Busy</option>";
376
377 tmphtml += "<option ";
378 if (lecturerStatus[n] == "") tmphtml += "selected ";
379 tmphtml += "value=''></option>";
380
381 return tmphtml;
382 }
void handleEduroam ()
AAAAAAAADHAAAAAAAADHServe menu for WPA2-ENTERPRISE setup.
Definition at line 477 of file Web.ino.
477 {
478 String s = "<h1>Wi-Fi Settings</h1><p><a href=\"/\">Go back</a></p><p>Please enter settings for eduroam (WPA2-Enterprise).</p><p>Password is typically left blank.</p><p>EAP Identity is typically your university email address.</p><p>EAP Password is typically your university password.</p>";
479 s += "<form method=\"get\" action=\"setap\">";
480 s += "<table><tr>";
481 s += "<td>SSID:</td><td><select name=\"ssid\"><option selected value=\"eduroam\">eduroam</option>";
482 s += ssidList;
483 s += "</select></td></tr><td>Password:<?td><td><input name=\"pass\" length=64 type=\"password\"></td></tr>";
484 s += "<tr><td>EAP Identity:</td><td><input name=\"eapidentity\" length=64></td></tr>";
485 s += "<tr><td>EAP Password:</td><td><input name=\"eappass\" length=64 type=\"password\"></td></tr>";
486 s += "<tr><td><input type=\"submit\"></td></tr></table></form>";
487 webServer.send(200, "text/html", makePage("Wi-Fi Settings", s));
488 }
void handleNotFound ()
AAAAAAAADIAAAAAAAADIServe error page if request is unhandled.
Definition at line 422 of file Web.ino.
422 {
423 String message = "File Not Found\n\n";
424 message += "URI: ";
425 message += webServer.uri();
426 message += "\nMethod: ";
427 message += (webServer.method() == HTTP_GET) ? "GET" : "POST";
428 message += "\nArguments: ";
429 message += webServer.args();
430 message += "\n";
431
432 for (uint8_t i = 0; i < webServer.args(); i++) {
433 message += " " + webServer.argName(i) + ": " + webServer.arg(i) + "\n";
434 }
435 webServer.send(404, "text/plain", message);
436 }
void handleReset ()
AAAAAAAADJAAAAAAAADJHandle user request to reset settings and reboot device.
Definition at line 439 of file Web.ino.
439 {
440 if (!webServer.authenticate(&www_username[0u], &www_password[0u])) {
441 return webServer.requestAuthentication();
442 webServer.send(200, "text/plain", "Login OK");
443 }
444 else {
445 SPIFFS.remove("/config.json");
446 String s = "<h1>Wi-Fi settings reset.</h1><p>The device will now restart.</p>";
447 s += "<p>Scan for and connect to the Setup access point.</p>";
448 s += "<p>You may now close this page.</p>";
449 webServer.send(200, "text/html", makePage("Reset Wi-Fi Settings", s));
450 delay(1000); //delay to finish serving the page before restart
451 ESP.restart();
452 }
453 }
void handleRoot ()
AAAAAAAADKAAAAAAAADKHandle requests to the main page of the config interface. Check authentication and serve page with current variables.
Definition at line 275 of file Web.ino.
275 {
276 if (!webServer.authenticate(&www_username[0u], &www_password[0u])) {
277 return webServer.requestAuthentication();
278 webServer.send(200, "text/plain", "Login OK");
279 }
280 else {
281 int sec = millis() / 1000;
282 int min = sec / 60;
283 int hr = min / 60;
284 char timestamp [100];
285 snprintf(timestamp, 100, "%02d:%02d:%02d", hr, min % 60, sec % 60);
286 float VBAT = ((200.0f / 100.0f) * 3.30f * float(analogRead(BATTMONPIN)) / 4095.0f) + 0.2f; // LiPo battery
287 int vbatt = (float)((100.0f / 4.2f) * VBAT);
288 String temp = "<html>\
289 <head>\
290 <title>Lecturer availability door announcer</title>\
291 <style>\
292 body { background-color: #cccccc; font-family: Arial, Helvetica, Sans-Serif; Color: #000088; }\
293 </style>\
294 </head>\
295 <body>\
296 <h1>Lecturer availability door announcer</h1>\
297 Final year BEng project by Chris Stubbs (2019)\
298 <h2>Status</h2>\
299 <p>Uptime: " + (String)timestamp + "</p>\
300 <p>Battery: " + (String)vbatt + "%, " + (String)VBAT + "V</p>\
301 <p>Free heap (RAM): " + ESP.getFreeHeap() + " bytes.</p>\
302 <h2>Settings</h2>\
303 <form action='/savesettings.do' method='post'>\
304 Sensor threshold: <input name='threshold' type='text' value='" + (String)thres + "'>\
305 <br /><br />\
306 Notify lecturer on ring even if they are busy?: <input name='busyNotif' type='checkbox'" + ((busyNotif) ? (" checked") : ("")) + ">\
307 <br /><br />\
308 Enable power saving sleep mode after <input name='sleepDelay' type='text' value='" + sleepDelay + "'> mins?: <input name='powerSave' type='checkbox'" + ((powerSave) ? (" checked") : ("")) + ">\
309 <br /><br />\
310 Room name: <input name='room' type='text' value='" + room + "'>\
311 <br /><br />\
312 Admin password: <input name='adminpw' type='text' value='" + www_password + "'>\
313 <br /><br />\
314 <table width='500'>\
315 <tr>\
316 <td>&nbsp;</td>\
317 <td>Lecturer 1</td>\
318 <td>Lecturer 2</td>\
319 <td>Lecturer 3</td>\
320 <td>Lecturer 4</td>\
321 <td>Lecturer 5</td>\
322 </tr>\
323 <tr>\
324 <td>Name</td>\
325 <td><input name='l1name' type='text' value='" + lecturerNames[0] + "'></td>\
326 <td><input name='l2name' type='text' value='" + lecturerNames[1] + "'></td>\
327 <td><input name='l3name' type='text' value='" + lecturerNames[2] + "'></td>\
328 <td><input name='l4name' type='text' value='" + lecturerNames[3] + "'></td>\
329 <td><input name='l5name' type='text' value='" + lecturerNames[4] + "'></td>\
330 </tr>\
331 <tr>\
332 <td>Key</td>\
333 <td><input name='l1key' type='text' value='" + lecturerIFTTkeys[0] + "'></td>\
334 <td><input name='l2key' type='text' value='" + lecturerIFTTkeys[1] + "'></td>\
335 <td><input name='l3key' type='text' value='" + lecturerIFTTkeys[2] + "'></td>\
336 <td><input name='l4key' type='text' value='" + lecturerIFTTkeys[3] + "'></td>\
337 <td><input name='l5key' type='text' value='" + lecturerIFTTkeys[4] + "'></td>\
338 </tr>\
339 <tr>\
340 <td>Status</td>\
341 <td>" + generateStatusDropdown(0) + "</td>\
342 <td>" + generateStatusDropdown(1) + "</td>\
343 <td>" + generateStatusDropdown(2) + "</td>\
344 <td>" + generateStatusDropdown(3) + "</td>\
345 <td>" + generateStatusDropdown(4) + "</td>\
346 </tr>\
347 </table>\
348 <input type='submit' value='Save'>\
349 </form>\
350 <br /><br />\
351 <p><a href='/reset'>Reset all settings and run Wi-Fi setup</a></p>\
352 </body>\
353 </html>";
354 webServer.send(200, "text/html", temp);
355 }
356 }
void handleSetAP ()
AAAAAAAADLAAAAAAAADLSave settings from setup wizard and restart to use them.
Definition at line 491 of file Web.ino.
491 {
492 ssid = urlDecode(webServer.arg("ssid"));
493 wifipsk = rot(urlDecode(webServer.arg("pass")));
494 EAP_IDENTITY = rot(urlDecode(webServer.arg("eapidentity")));
495 EAP_PASSWORD = rot(urlDecode(webServer.arg("eappass")));
496 saveConfig();
497
498 String s = "<h1>Setup complete.</h1><p>Device will be connected to \"";
499 s += ssid;
500 s += "\" after the restart.</p>";
501 s += "<p>Check the IP address displayed on the device and access this page from your web browser to continue the setup process.</p>";
502 s += "<p>The username and password for the settings portal will be " + www_username + "/" + www_password + ".</p>";
503
504 s += "<p>You may now close this page.</p>";
505 webServer.send(200, "text/html", makePage("Wi-Fi Settings", s));
506 delay(1000); //delay to finish serving the page before restart
507 ESP.restart();
508 }
void handleSettings ()
AAAAAAAADMAAAAAAAADMServe menu for WPA2-PSK setup.
Definition at line 465 of file Web.ino.
465 {
466 String s = "<h1>Wi-Fi Settings</h1><p><a href=\"/\">Go back</a></p><p>Please enter settings for standard WiFi (WPA2).</p>";
467 s += "<form method=\"get\" action=\"setap\">";
468 s += "<table><tr>";
469 s += "<td>SSID:</td><td><select name=\"ssid\">";
470 s += ssidList;
471 s += "</select></td></tr><td>Password:</td><td><input name=\"pass\" length=64 type=\"password\"></td></tr>";
472 s += "<tr><td><input type=\"submit\"></td></tr></table></form>";
473 webServer.send(200, "text/html", makePage("Wi-Fi Settings", s));
474 }
void handleSetupRoot ()
AAAAAAAADNAAAAAAAADNServe main menu of setup wizard (WPA2-PSK / WPA2-ENTERPRISE).
Definition at line 456 of file Web.ino.
456 {
457 String s = "<h1>Lecturer availability door announcer</h1>";
458 s += "<p>Final year BEng project by Chris Stubbs (2019)</p>";
459 s += "<p><a href=\"/settings\">Setup wizard for standard WiFi (WPA2)</a></p>";
460 s += "<p><a href=\"/eduroam\">Setup wizard for eduroam (WPA2-Enterprise)</a></p>";
461 webServer.send(200, "text/html", makePage("Setup Wizard", s));
462 }
String makePage (String title, String contents)
AAAAAAAADOAAAAAAAADOGenerate basic HTML tags around content.
Definition at line 227 of file Web.ino.
227 {
228 String s = "<!DOCTYPE html><html><head>";
229 s += "<meta name=\"viewport\" content=\"width=device-width,user-scalable=0\">";
230 s += "<title>Lecturer availability door announcer</title>";
231 s += "<style> body { background-color: #cccccc; font-family: Arial, Helvetica, Sans-Serif; Color: #000088; } </style>";
232 s += "</head><body>";
233 s += contents;
234 s += "</body></html>";
235 return s;
236 }
void ring (const int bus)
AAAAAAAADPAAAAAAAADPSend a webhooks request to IFTTT with the room name and appropraite lecturers key. Display status on screen. Input = 0...7.
Definition at line 20 of file Web.ino.
21 {
22 lastPressed = millis(); //record the button was pressed for sleep mode
23 if (lecturerStatus[bus] == "Available") {
24 digitalWrite(LEDAVAILPIN, HIGH);
25 } else {
26 digitalWrite(LEDBUSYPIN, HIGH);
27 }
28 if (lecturerStatus[bus] == "Available" or busyNotif)
29 {
30 display.setRotation(1);
31 display.fillScreen(GxEPD_WHITE);
32 display.setTextColor(GxEPD_BLACK);
33 display.setFont(font);
34 display.setCursor(0, 16 * 4);
35 display.print("Contacting "); display.print(lecturerNames[bus]); display.println("...");
36 display.update();
37 if ((WiFi.status() == WL_CONNECTED)) {
38 HTTPClient http;
39 Serial.println((String)"[INFO] HTTP Req: https://maker.ifttt.com/trigger/" + room + "/with/key/" + lecturerIFTTkeys[bus]);
40 http.begin((String)"https://maker.ifttt.com/trigger/" + room + "/with/key/" + lecturerIFTTkeys[bus]);
41 int httpCode = http.GET();
42 if (httpCode > 0) {
43 String payload = http.getString();
44 Serial.println((String)"[INFO] httpCode: " + httpCode);
45 Serial.println((String)"[INFO] payload: " + payload);
46 if (httpCode != 200) {
47 //Error communicating with IFTTT service.
48 if (httpCode == 302) {
49 //"Temporarily moved" (common error for no key)
50 errorMsg("Error communicating with \nIFTTT.\n\nDid you set the room and\nlecturer key?");
51 }
52 errorMsg("Error communicating with IFTTT " + (String)httpCode + " " + payload);
53 errorMsg("Req: " + (String)"https://maker.ifttt.com/trigger/" + room + "/with/key/" + lecturerIFTTkeys[bus]);
54 }
55 if (httpCode == 200) {
56 //success
57 digitalWrite(LEDOKPIN, HIGH);
58 display.setRotation(1);
59 display.fillScreen(GxEPD_WHITE);
60 display.setTextColor(GxEPD_BLACK);
61 display.setFont(font);
62 display.setCursor(0, 16 * 4);
63 if (lecturerStatus[bus] == "Available") {
64 display.println(wordWrap(lecturerNames[bus] + " has been notified."));
65 } else {
66 display.println(wordWrap(lecturerNames[bus] + " has been notified, but may be busy."));
67 }
68 display.update();
69 }
70 }
71 else {
72 errorMsg("Unknown error in HTTP request.");
73 }
74 http.end(); //Free the resources
75 } else {
76 errorMsg("Wifi not connected. Restarting in 30 seconds.");
77 delay(30000);
78 ESP.restart();
79 }
80 delay(5000);
81 digitalWrite(LEDOKPIN, LOW);
82 digitalWrite(LEDAVAILPIN, LOW);
83 digitalWrite(LEDBUSYPIN, LOW);
84 writeNames();
85 } else {
86 display.setRotation(1);
87 display.fillScreen(GxEPD_WHITE);
88 display.setTextColor(GxEPD_BLACK);
89 display.setFont(font);
90 display.setCursor(0, 16 * 4);
91 display.println(wordWrap((String)lecturerNames[bus] + " is busy/away."));
92 display.println("Please try again later.");
93 display.update();
94 delay(3000);
95 digitalWrite(LEDOKPIN, LOW);
96 digitalWrite(LEDAVAILPIN, LOW);
97 digitalWrite(LEDBUSYPIN, LOW);
98 writeNames();
99 }
100 }
void saveSettings ()
AAAAAAAADQAAAAAAAADQSave settings recieved from the web config interface to SPIFFS and load them into current memory.
Definition at line 385 of file Web.ino.
385 {
386 if (!webServer.authenticate(&www_username[0u], &www_password[0u])) {
387 return webServer.requestAuthentication();
388 webServer.send(200, "text/plain", "Login OK");
389 }
390 else {
391 room = webServer.arg("room");
392 busyNotif = (webServer.arg("busyNotif") == "on"); //true if checked
393 powerSave = (webServer.arg("powerSave") == "on"); //true if checked
394 thres = webServer.arg("threshold").toFloat();
395 sleepDelay = webServer.arg("sleepDelay").toInt();
396 www_password = webServer.arg("adminpw");
397 lecturerNames[0] = webServer.arg("l1name");
398 lecturerNames[1] = webServer.arg("l2name");
399 lecturerNames[2] = webServer.arg("l3name");
400 lecturerNames[3] = webServer.arg("l4name");
401 lecturerNames[4] = webServer.arg("l5name");
402 lecturerIFTTkeys[0] = webServer.arg("l1key");
403 lecturerIFTTkeys[1] = webServer.arg("l2key");
404 lecturerIFTTkeys[2] = webServer.arg("l3key");
405 lecturerIFTTkeys[3] = webServer.arg("l4key");
406 lecturerIFTTkeys[4] = webServer.arg("l5key");
407 lecturerStatus[0] = webServer.arg("l1status");
408 lecturerStatus[1] = webServer.arg("l2status");
409 lecturerStatus[2] = webServer.arg("l3status");
410 lecturerStatus[3] = webServer.arg("l4status");
411 lecturerStatus[4] = webServer.arg("l5status");
412 String out = "";
413 out += "Saved!\n";
414 out += "<a href='/'>Go back</a>\n";
415 webServer.send(200, "text/html", out);
416 saveConfig(); //commit new settings to config file
417 writeNames(); //update the display
418 }
419 }
void setupMode ()
AAAAAAAADRAAAAAAAADRPrepare and start the setup wizard with list of scanned SSIDs.
Definition at line 196 of file Web.ino.
196 {
197 //Disconnect any connections and scan for AP's
198 WiFi.mode(WIFI_STA);
199 WiFi.disconnect();
200 delay(100);
201 int n = WiFi.scanNetworks();
202 delay(100);
203 Serial.println("");
204 for (int i = 0; i < n; ++i) {
205 ssidList += "<option value=\"";
206 ssidList += WiFi.SSID(i);
207 ssidList += "\">";
208 ssidList += WiFi.SSID(i);
209 ssidList += "</option>";
210 }
211 delay(100);
212 //Create config AP
213 WiFi.mode(WIFI_AP);
214 delay(250);
215 WiFi.softAPConfig(apIP, apIP, IPAddress(255, 255, 255, 0));
216 delay(250);
217 WiFi.softAP(apSSID);
218 delay(250);
219 dnsServer.setErrorReplyCode(DNSReplyCode::NoError);
220 dnsServer.start(53, "*", apIP);
221 Serial.println((String)"[INFO] DNS server started");
222 startWebServer();
223 Serial.println((String)"[INFO] Starting Access Point at " + apSSID);
224 }
void startWebServer ()
AAAAAAAADSAAAAAAAADSStart the appropriate web server depending on if the mode is normal or setup mode.
Definition at line 175 of file Web.ino.
175 {
176 if (settingMode) { //Set up webserver to serve captive portal for wifi setup wizard
177 setupMsg(apSSID); //Display setup screen
178 webServer.on("/settings", handleSettings);
179 webServer.on("/eduroam", handleEduroam);
180 webServer.on("/setap", handleSetAP);
181 webServer.onNotFound(handleSetupRoot);
182 }
183 else { //Set up webserver to serve normal setup page
184 Serial.print("[INFO] Starting Web Server at ");
185 Serial.println(WiFi.localIP().toString());
186 addToLog((String)"IP addr: " + WiFi.localIP().toString());
187 webServer.on("/", handleRoot);
188 webServer.on("/reset", handleReset);
189 webServer.on("/savesettings.do", saveSettings);
190 webServer.onNotFound(handleNotFound);
191 }
192 webServer.begin();
193 }
String urlDecode (String input)
AAAAAAAADTAAAAAAAADTReplace URL encoded characters.
Definition at line 239 of file Web.ino.
239 {
240 String s = input;
241 s.replace("%20", " ");
242 s.replace("+", " ");
243 s.replace("%21", "!");
244 s.replace("%22", "\"");
245 s.replace("%23", "#");
246 s.replace("%24", "$");
247 s.replace("%25", "%");
248 s.replace("%26", "&");
249 s.replace("%27", "\'");
250 s.replace("%28", "(");
251 s.replace("%29", ")");
252 s.replace("%30", "*");
253 s.replace("%31", "+");
254 s.replace("%2C", ",");
255 s.replace("%2E", ".");
256 s.replace("%2F", "/");
257 s.replace("%2C", ",");
258 s.replace("%3A", ":");
259 s.replace("%3A", ";");
260 s.replace("%3C", "<");
261 s.replace("%3D", "=");
262 s.replace("%3E", ">");
263 s.replace("%3F", "?");
264 s.replace("%40", "@");
265 s.replace("%5B", "[");
266 s.replace("%5C", "\\");
267 s.replace("%5D", "]");
268 s.replace("%5E", "^");
269 s.replace("%5F", "-");
270 s.replace("%60", "`");
271 return s;
272 }
void wifiTasks ()
AAAAAAAADUAAAAAAAADURun background WiFi DNS server and webserver tasks.
Definition at line 12 of file Web.ino.
12 {
13 if (settingMode) {
14 dnsServer.processNextRequest();
15 }
16 webServer.handleClient();
17 }

Variable Documentation
const char* apSSID = "_SETUP"
AAAAAAAADVAAAAAAAADV
Name of SSID for setup wizard access point.
Definition at line 8 of file Web.ino.
String ssidList
AAAAAAAADWAAAAAAAADW
List of all detected SSIDs from scan.
Definition at line 9 of file Web.ino.

Index
INDEX

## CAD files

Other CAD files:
PCB/Daughterboard/Daughterboard.skp
PCB/Mainboard/Mainboard.skp

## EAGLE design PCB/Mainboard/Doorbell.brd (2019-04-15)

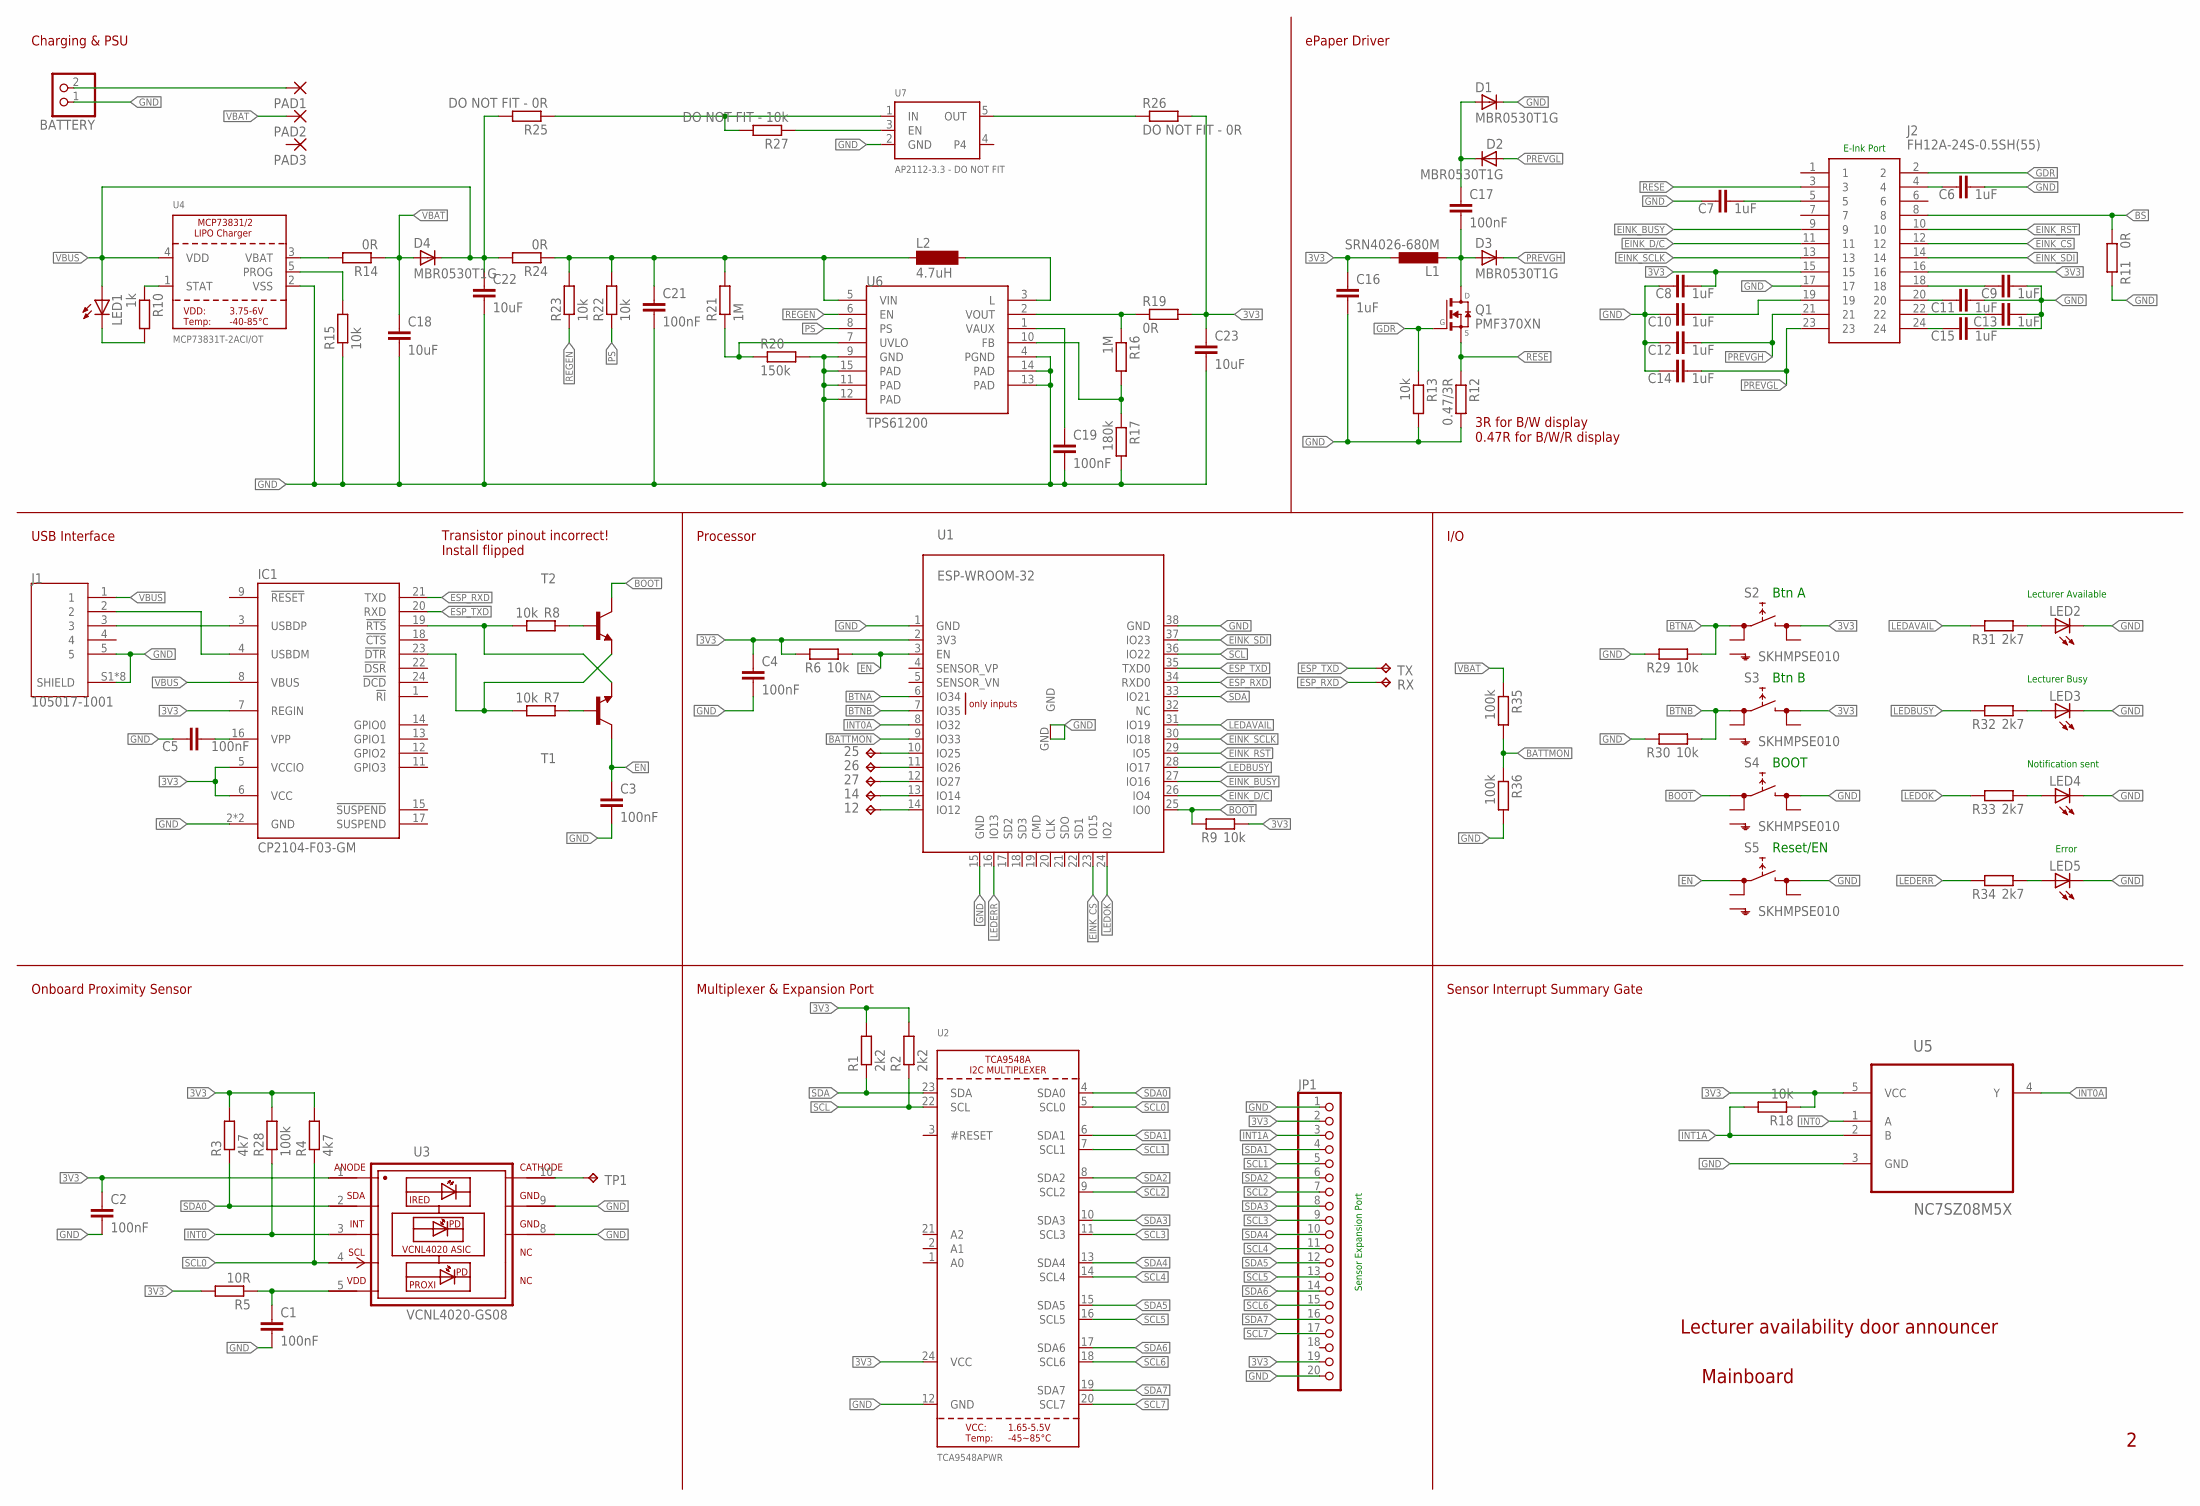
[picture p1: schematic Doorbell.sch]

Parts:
12, 14, 25, 26, 27: TPB1,27; B1,27
BATTERY: PINHD-1X2/90; 1X02/90
C1, C2, C3, C4, C5, C17, C19, C21: 100nF; C0603
C6, C7, C8, C9, C10, C11, C12, C13, C14, C15, C16: 1uF; C0603
C18, C22, C23: 10uF; C1206
D1, D2, D3, D4: MBR0530T1G; SOD123
IC1: CP2104-F03-GM; QFN24-PAD
J1: 105017-1001; MOLEX_105017-1001
J2: FH12A-24S-0.5SH(55); FH12A-24S-0.5SH
JP1: PINHD-1X20/90; 1X20/90
L1: SRN4026-680M; L4532P
L2: 4.7uH; MS50
LED1, LED2, LED3, LED4, LED5: LEDSML0603; SML0603
PAD1, PAD2, PAD3: WIREPADSMD1,27-254; SMD1,27-2,54
Q1: PMF370XN; SOT323-R
R1, R2: 2k2; R0603
R3, R4: 4k7; R0603
R5: 10R; R0603
R6, R7, R8, R9, R13, R15, R18, R22, R23, R29, R30: 10k; R0603
R10: 1k; R0603
R11, R14, R19, R24: 0R; R0603
R12: 0.47/3R; R0603
R16, R21: 1M; R0603
R17: 180k; R0603
R20: 150k; R0603
R25, R26: DO NOT FIT - 0R; R0603
R27: DO NOT FIT - 10k; R0603
R28, R35, R36: 100k; R0603
R31, R32, R33, R34: 2k7; R0603
RX: TPB1,27; B1,27
S2, S3, S4, S5: SKHMPSE010; SKHMPXE010
T1, T2: -NPN-SOT23-EBC; SOT23-EBC
TP1: TPB1,27; B1,27
TX: TPB1,27; B1,27
U1: ESP-WROOM-32
U2: TCA9548APWR; TSSOP24
U3: VCNL4020-GS08; PHODET_VCNL4020
U4: MCP73831T-2ACI/OT; SOT23-5
U5: NC7SZ08M5X; SOT95P280X145-5N; DIGI-KEY_PART_NUMBER NC7SZ08M5XCT-ND
U6: TPS61200; QFN-10_PAD
U7: AP2112-3.3 - DO NOT FIT; SOT23-5

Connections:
3V3: C2.1, C4.1, C8.2, C16.1, C23.1, IC1.5 (VCCIO), IC1.6 (VCC), IC1.7 (REGIN), J2.15, J2.16, JP1.2, JP1.19, L1.1, R1.2, R2.2, R3.2, R4.2, R5.2, R6.2, R9.1, R18.1, R19.2, R26.2, R28.2, S2.3 (2.1), S3.3 (2.1), U1.2 (3V3), U2.24 (VCC), U3.1 (IR-ANODE), U5.5 (VCC)
BATTMON: R35.2, R36.1, U1.9 (IO33)
BOOT: R9.2, S4.1 (1.1), T2.C, U1.25 (IO0)
BS: J2.8, R11.1
BTNA: R29.1, S2.1 (1.1), U1.6 (IO34)
BTNB: R30.1, S3.1 (1.1), U1.7 (IO35)
DTR: IC1.23 (!DTR), R7.1, T2.E
EINK_BUSY: J2.9, U1.27 (IO16)
EINK_CS: J2.12, U1.23 (IO15)
EINK_D/C: J2.11, U1.26 (IO4)
EINK_RST: J2.10, U1.29 (IO5)
EINK_SCLK: J2.13, U1.30 (IO18)
EINK_SDI: J2.14, U1.37 (IO23)
EN: C3.1, R6.1, S5.1 (1.1), T1.C, U1.3 (EN)
ESP_RXD: IC1.21 (TXD), RX.TP, U1.34 (RXD0)
ESP_TXD: IC1.20 (RXD), TX.TP, U1.35 (TXD0)
GDR: J2.2, Q1.1 (G), R13.1
GND: BATTERY.1, C1.2, C2.2, C3.2, C4.2, C5.1, C6.2, C7.1, C8.1, C9.2, C10.1, C11.2, C12.1, C13.2, C14.1, C15.2, C16.2, C18.2, C19.2, C21.2, C22.2, C23.2, D1.1 (C), IC1.2 (GND), IC1.TP (GND), J1.5, J1.S1 (SHIELD), J1.S1.1 (SHIELD), J1.S2 (SHIELD), J1.S2.1 (SHIELD), J1.S3 (SHIELD), J1.S4 (SHIELD), J1.S5 (SHIELD), J1.S6 (SHIELD), J2.17, JP1.1, JP1.20, LED2.C, LED3.C, LED4.C, LED5.C, R11.2, R12.2, R13.2, R15.1, R17.2, R20.2, R29.2, R30.2, R36.2, S4.3 (2.1), S5.3 (2.1), U1.1 (GND), U1.15 (GND), U1.38 (GND), U1.GND, U2.12 (GND), U3.8 (GND2), U3.9 (GND), U4.2 (VSS), U5.3 (GND), U6.4 (PGND), U6.9 (GND), U6.11 (PAD), U6.12 (PAD), U6.13 (PAD), U6.14 (PAD), U6.15 (PAD), U7.2 (GND)
INT0: R28.1, U3.3 (INT), U5.1 (A)
INT0A: U1.8 (IO32), U5.4 (Y)
INT1A: JP1.3, R18.2, U5.2 (B)
LEDAVAIL: R31.2, U1.31 (IO19)
LEDBUSY: R32.2, U1.28 (IO17)
LEDERR: R34.2, U1.16 (IO13)
LEDOK: R33.2, U1.24 (IO2)
unnamed: TP1.TP, U3.10 (IR-CATHODE)
unnamed: C1.1, R5.1, U3.5 (VDD)
unnamed: R7.2, T1.B
unnamed: R16.1, R19.1, U6.2 (VOUT)
unnamed: R8.2, T2.B
unnamed: IC1.4 (USBDM), J1.2
unnamed: IC1.3 (USBDP), J1.3
unnamed: C5.2, IC1.16 (VPP)
unnamed: C17.1, D1.2 (A), D2.1 (C)
unnamed: R10.1, U4.1 (STAT)
unnamed: C10.2, J2.19
unnamed: C17.2, D3.2 (A), L1.2, Q1.3 (D)
unnamed: LED1.C, R10.2
unnamed: C15.1, J2.24
unnamed: C13.1, J2.22
unnamed: C11.1, J2.20
unnamed: C9.1, J2.18
unnamed: C6.1, J2.4
unnamed: C7.2, J2.5
unnamed: R14.2, U4.3 (VBAT)
unnamed: R15.2, U4.5 (PROG)
unnamed: BATTERY.2, PAD1.1
unnamed: R16.2, R17.1, U6.10 (FB)
unnamed: C19.1, U6.1 (VAUX)
unnamed: 12.TP, U1.14 (IO12)
unnamed: R20.1, R21.1, U6.7 (UVLO)
unnamed: L2.2, U6.3 (L)
unnamed: R25.1, R27.2, U7.1 (IN)
unnamed: 14.TP, U1.13 (IO14)
unnamed: R27.1, U7.3 (EN)
unnamed: 25.TP, U1.10 (IO25)
unnamed: 26.TP, U1.11 (IO26)
unnamed: 27.TP, U1.12 (IO27)
unnamed: LED5.A, R34.1
unnamed: LED4.A, R33.1
unnamed: LED3.A, R32.1
unnamed: LED2.A, R31.1
OUT: R26.1, U7.5 (OUT)
PREVGH: C12.2, D3.1 (C), J2.21
PREVGL: C14.2, D2.2 (A), J2.23
PS: R22.1, U6.8 (PS)
REGEN: R23.1, U6.6 (EN)
RESE: J2.3, Q1.2 (S), R12.1
RTS: IC1.19 (!RTS), R8.1, T1.E
SCL: R2.1, U1.36 (IO22), U2.22 (SCL)
SCL0: R4.1, U2.5 (SCL0), U3.4 (SCL)
SCL1: JP1.5, U2.7 (SCL1)
SCL2: JP1.7, U2.9 (SCL2)
SCL3: JP1.9, U2.11 (SCL3)
SCL4: JP1.11, U2.14 (SCL4)
SCL5: JP1.13, U2.16 (SCL5)
SCL6: JP1.15, U2.18 (SCL6)
SCL7: JP1.17, U2.20 (SCL7)
SDA: R1.1, U1.33 (IO21), U2.23 (SDA)
SDA0: R3.1, U2.4 (SDA0), U3.2 (SDA)
SDA1: JP1.4, U2.6 (SDA1)
SDA2: JP1.6, U2.8 (SDA2)
SDA3: JP1.8, U2.10 (SDA3)
SDA4: JP1.10, U2.13 (SDA4)
SDA5: JP1.12, U2.15 (SDA5)
SDA6: JP1.14, U2.17 (SDA6)
SDA7: JP1.16, U2.19 (SDA7)
VBAT: C18.1, D4.2 (A), PAD2.1, R14.1, R35.1
VBUS: C22.1, D4.1 (C), IC1.8 (VBUS), J1.1, LED1.A, R24.2, R25.2, U4.4 (VDD)
VIN: C21.1, L2.1, R21.2, R22.2, R23.2, R24.1, U6.5 (VIN)

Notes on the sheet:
Sensor Expansion Port
E-Ink Port
Btn A
Btn B
BOOT
Reset/EN
Lecturer Available
Lecturer Busy
Notification sent
Error
Onboard Proximity Sensor
Multiplexer & Expansion Port
Sensor Interrupt Summary Gate
I/O
Processor
USB Interface
Charging & PSU
ePaper Driver
Mainboard
Lecturer availability door announcer
3R for B/W display 0.47R for B/W/R display
Transistor pinout incorrect! Install flipped

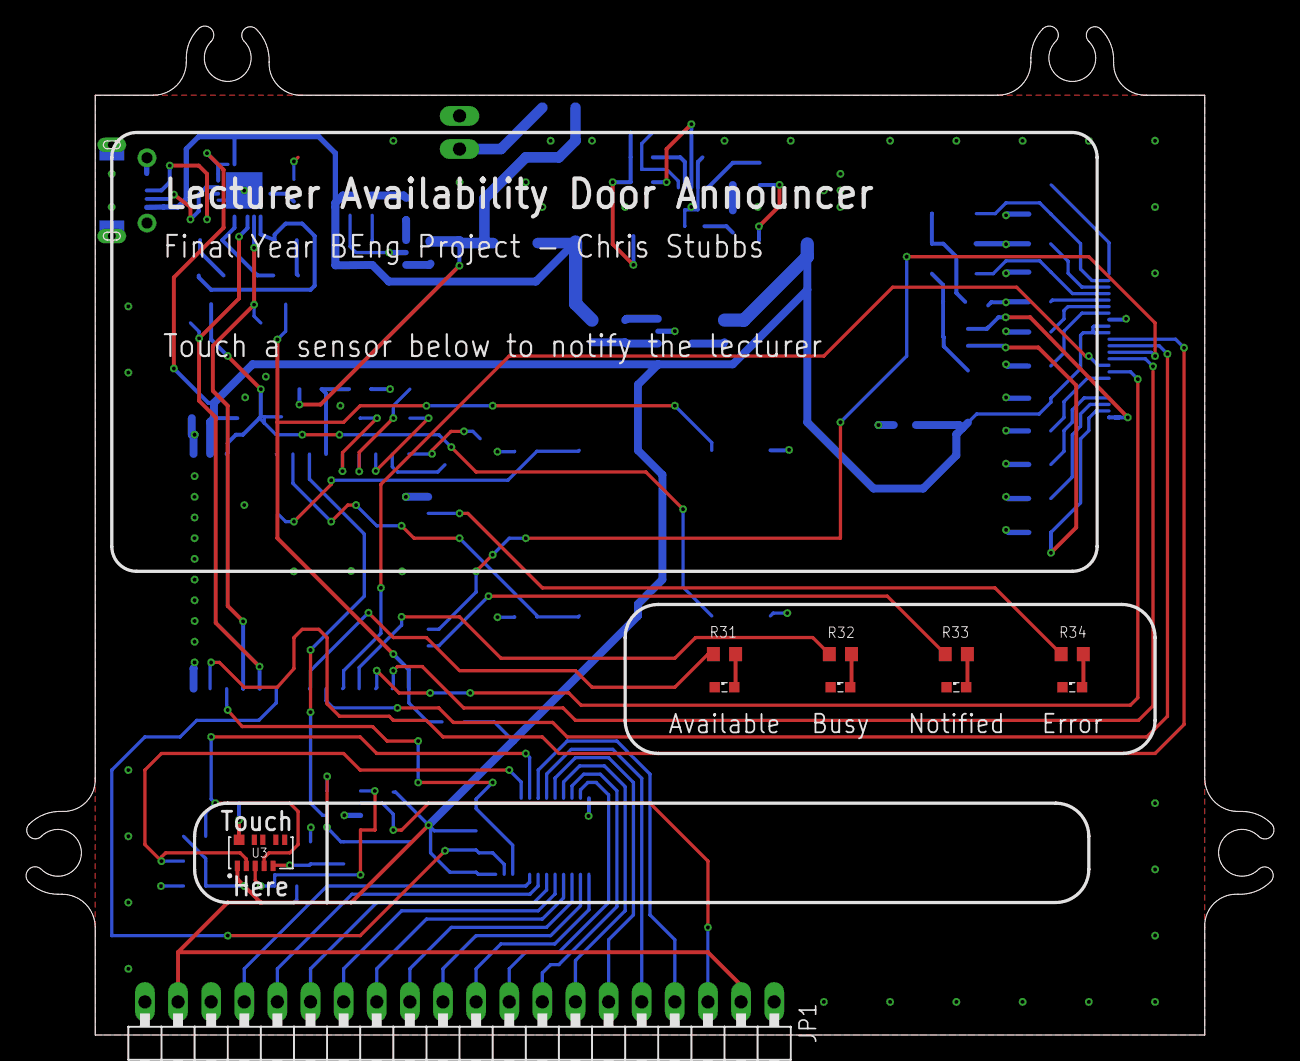
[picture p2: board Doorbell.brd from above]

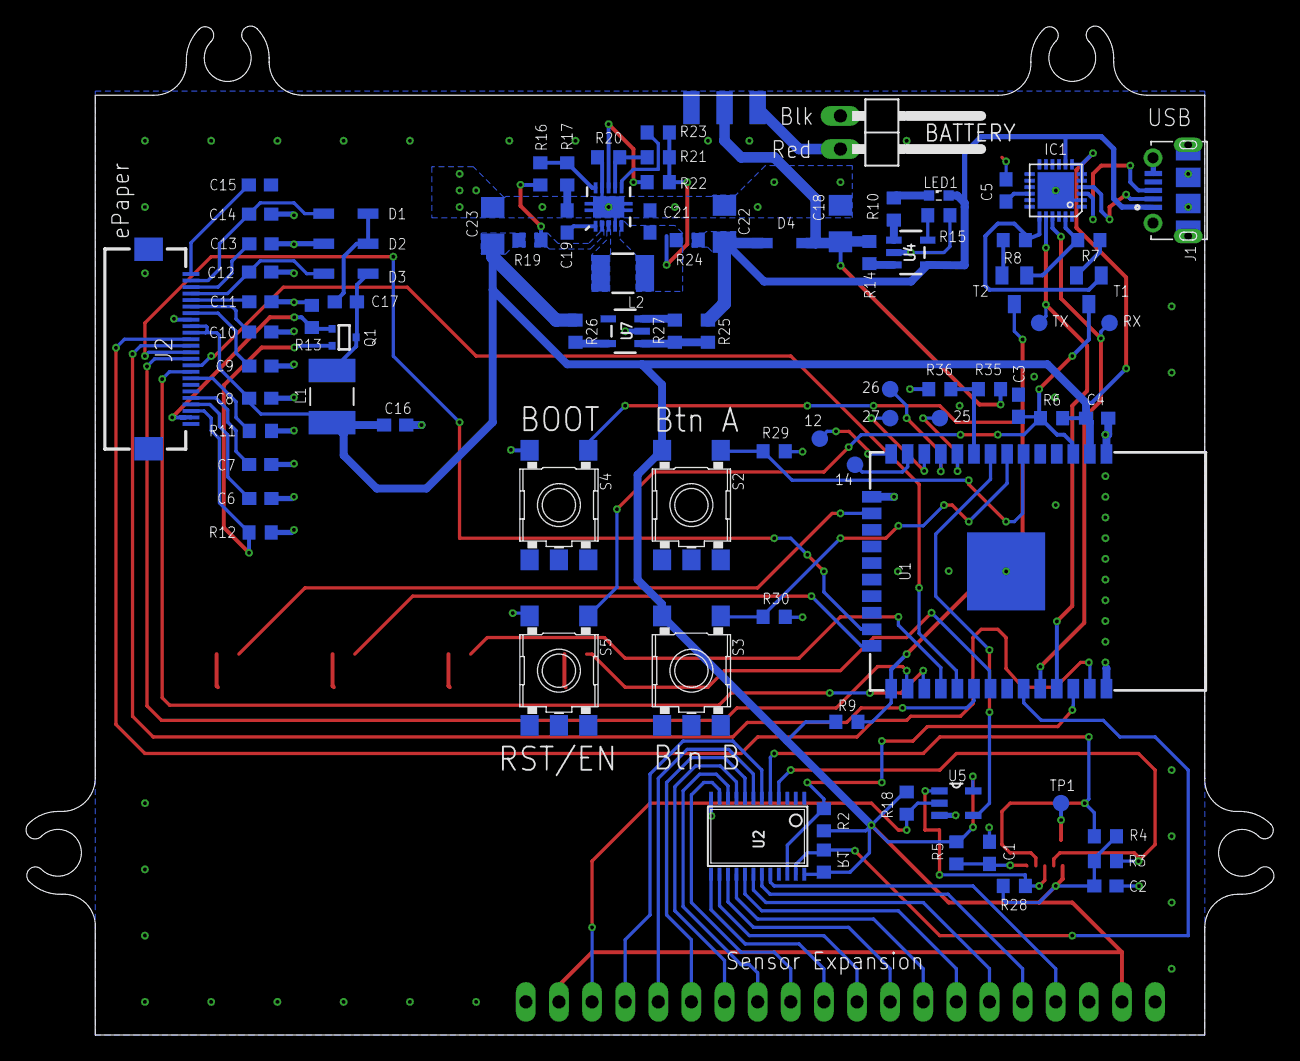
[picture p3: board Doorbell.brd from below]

Board: 2 copper layers, 95.7 x 77.4 mm, 99 parts (89 on the bottom side), 90 nets.

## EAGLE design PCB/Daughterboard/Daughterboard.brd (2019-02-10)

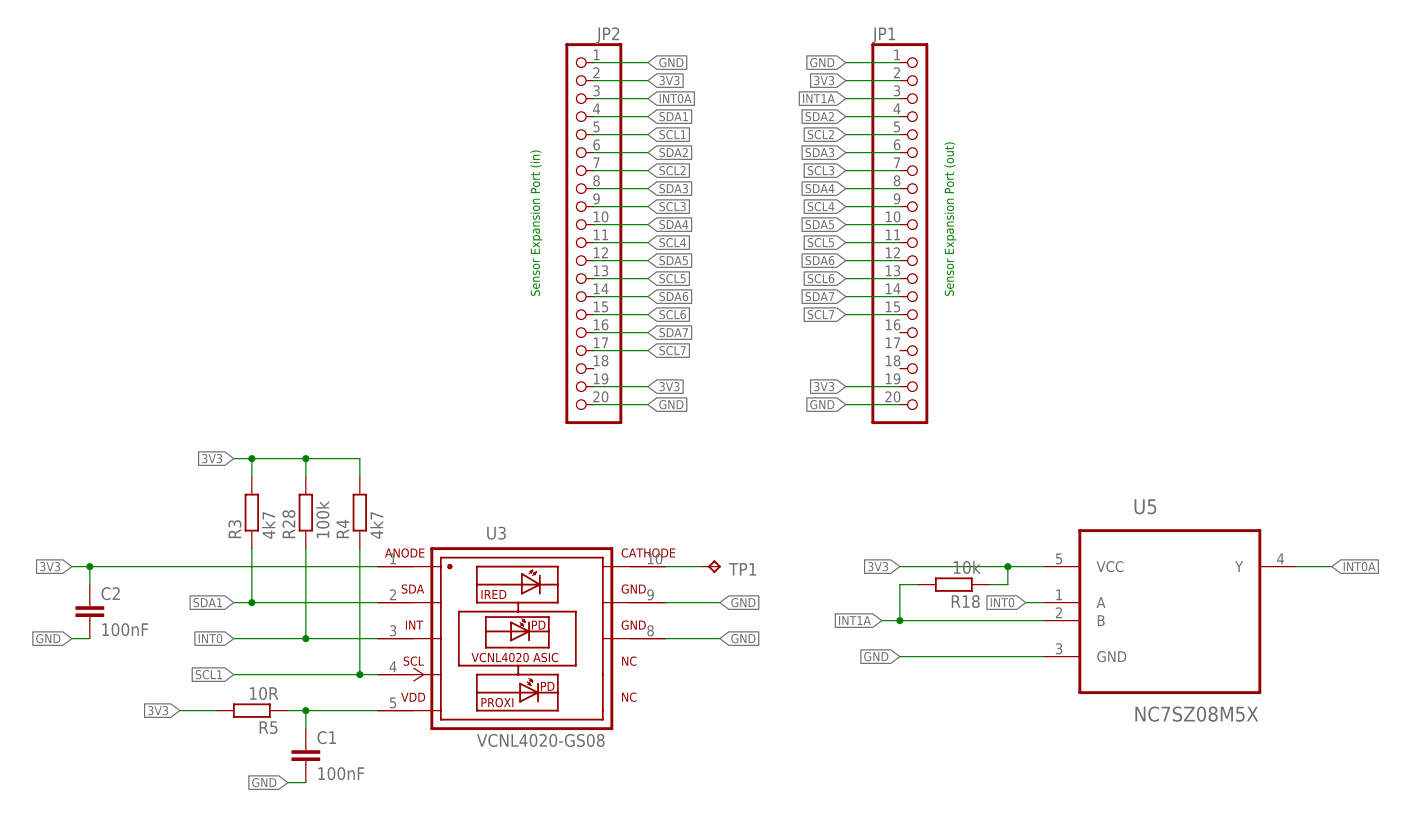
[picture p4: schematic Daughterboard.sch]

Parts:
C1, C2: 100nF; C0603
JP1, JP2: PINHD-1X20/90; 1X20/90
R3, R4: 4k7; R0603
R5: 10R; R0603
R18: 10k; R0603
R28: 100k; R0603
TP1: TPB1,27; B1,27
U3: VCNL4020-GS08; PHODET_VCNL4020
U5: NC7SZ08M5X; SOT95P280X145-5N; DIGI-KEY_PART_NUMBER NC7SZ08M5XCT-ND

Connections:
3V3: C2.1, JP1.2, JP1.19, JP2.2, JP2.19, R3.2, R4.2, R5.2, R18.1, R28.2, U3.1 (IR-ANODE), U5.5 (VCC)
GND: C1.2, C2.2, JP1.1, JP1.20, JP2.1, JP2.20, U3.8 (GND2), U3.9 (GND), U5.3 (GND)
INT0: R28.1, U3.3 (INT), U5.1 (A)
INT0A: JP2.3, U5.4 (Y)
INT1A: JP1.3, R18.2, U5.2 (B)
unnamed: TP1.TP, U3.10 (IR-CATHODE)
unnamed: C1.1, R5.1, U3.5 (VDD)
SCL1: JP2.5, R4.1, U3.4 (SCL)
SCL2: JP1.5, JP2.7
SCL3: JP1.7, JP2.9
SCL4: JP1.9, JP2.11
SCL5: JP1.11, JP2.13
SCL6: JP1.13, JP2.15
SCL7: JP1.15, JP2.17
SDA1: JP2.4, R3.1, U3.2 (SDA)
SDA2: JP1.4, JP2.6
SDA3: JP1.6, JP2.8
SDA4: JP1.8, JP2.10
SDA5: JP1.10, JP2.12
SDA6: JP1.12, JP2.14
SDA7: JP1.14, JP2.16

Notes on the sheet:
Sensor Expansion Port (out)
Sensor Expansion Port (in)

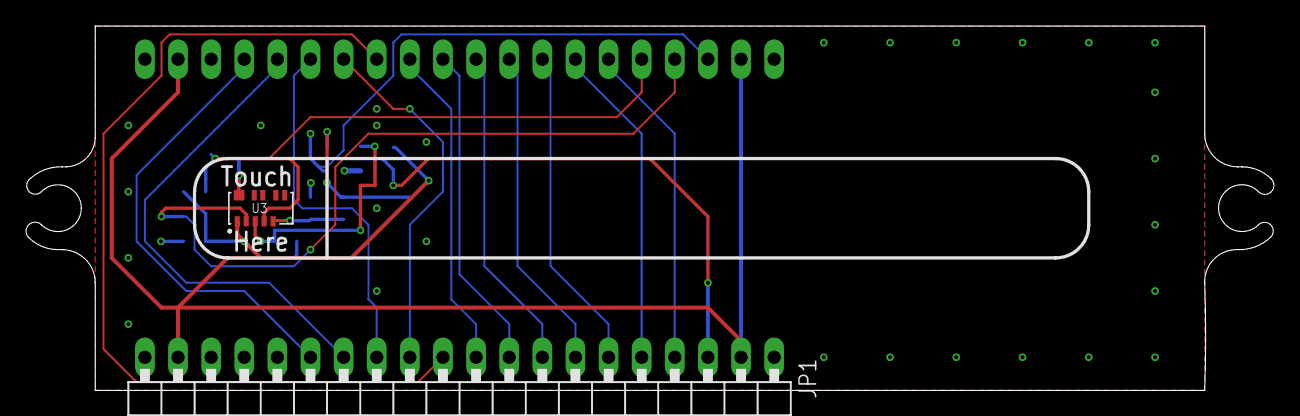
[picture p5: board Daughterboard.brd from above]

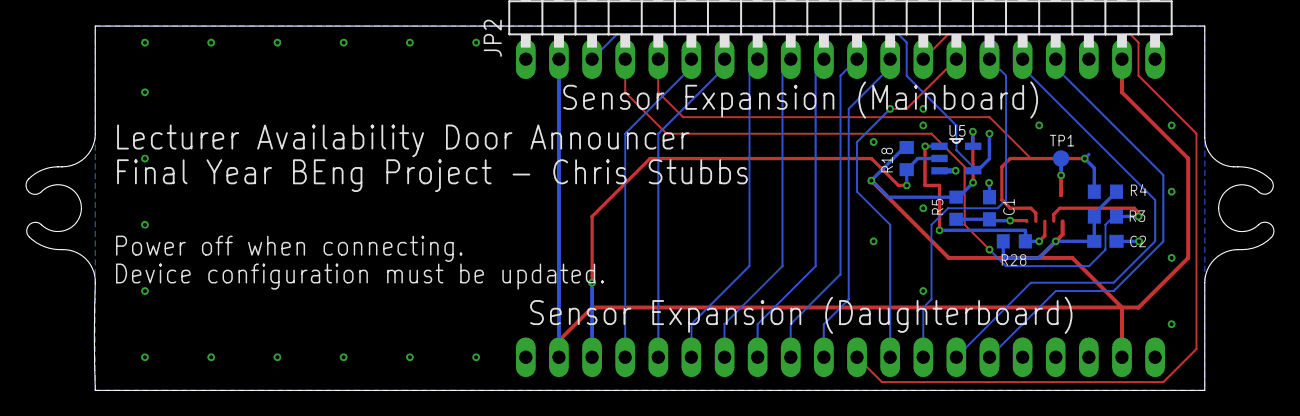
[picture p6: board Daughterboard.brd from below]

Board: 2 copper layers, 95.7 x 27.9 mm, 12 parts (10 on the bottom side), 21 nets.

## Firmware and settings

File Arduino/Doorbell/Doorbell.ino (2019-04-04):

/**
    \file Doorbell.ino
    Main file for the Lecturer Availability Door Announcer final year BEng project by Chris Stubbs.
*/

#define VERSION "1.1"//update when comitted to github

#include <WiFi.h>
#include <DNSServer.h>
#include <WiFiClient.h>
#include <WebServer.h>
#include "esp_wpa2.h"
#include <ArduinoJson.h>
#include "Settings.h" //Initial settings
#include "bitmaps.h"
#include <HTTPClient.h>
#include "SPIFFS.h"
#include <Wire.h>
#include "Adafruit_VCNL4010.h"
#include <GxEPD.h>
#include <GxIO/GxIO.h>
#include <GxIO/GxIO_SPI/GxIO_SPI.h>
#include <GxGDEH029A1/GxGDEH029A1.h>      // select the display class to use: 2.9" b/w
#include <Fonts/FreeMonoBold9pt7b.h>
#include <Fonts/FreeMonoBold12pt7b.h>

GxIO_Class io(SPI, /*! CS */ 15, /*! DC */ 4, /*! RST */ 5); //!< Define the hardware pins used by the ePaper display for SPI. 15=CS, 4=DC, 5=RST.
GxEPD_Class display(io, /*!RST*/ 5, /*!BUSY*/ 16); //!< Define the hardware pins used by the ePaper display for control. 5=RST, 16=BUSY..
DNSServer dnsServer; //!< DNS server used for captive portal in setup mode.
WebServer webServer(80); //!< Web server used for setup wizard and config interface.
boolean settingMode; //!< Is the device in setup wizard mode (true) or normal mode (false)?
int doorbells = 0;  //!< Number of VCNL4020 sensors detected.
bool sleeping = false; //!< Is the device in or about to enter deep sleep mode for power saving?

/*! Setup function runs once on startup. Detect boot mode (normal or waking up from deep sleep). Perform setup. */
void setup() {
  Wire.begin();
  Serial.begin(115200);
  Serial.println((String)"[INFO] Lecturer availability door announcer version " + (String)VERSION);
  wakeup_reason();
  display.init();
  initGPIO();
  if (bootmode() == 6) displayVersion();
  initFS();
  bool configstatus = loadConfig();
  if (bootmode() == 3) { //wakeup cause by timer. Update battery % on screen and go back to sleep.
    sleeping = true; //set the sleeping flag
    writeNames(); //show the sleeping flag on screen
    entersleep(); //go to sleep
  }
  if (configstatus) {
    //Config loaded OK. Try to connect to WiFi.
    if (connectWiFi()) {
      //WiFi connected OK. Start config web server and continue boot.
      startWebServer();
    } else {
      //WiFi failed to connect. Start setup mode and abort boot.
      setupMode();
      return;
    }
  }
  else {
    setupMode();
    return; //abort boot to carry out initial setup wizard
  }
  detectVCNLs();
  if (bootmode() == 1) {
    int source = interruptSource();
    Serial.println((String)"[INFO] Interrupt triggered by sensor " + interruptSource());
    ring(source);
  }
  calibrateVCNLs();
  writeNames();
}

/*! Loop function runs continuously. Poll devices and run background tasks. */
void loop() {
  wifiTasks();
  scanVCNLs();
  checkButtons();
  manageSleep();
  delay(SCAN_INTERVAL);
}

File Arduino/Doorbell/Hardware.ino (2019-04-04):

/**
    \file Hardware.ino
    Handles I2C multiplexer, connection to VCNL IR proximity sensors, proximity sensor related functions, initialisation of GPIO, scanning of buttons.
*/

//======================Variables for VCNL==============================
long average[] =   {0, 0, 0, 0, 0, 0, 0, 0}; //!< Array of average reading of all sensors.
long threshold[] = {0, 0, 0, 0, 0, 0, 0, 0}; //!< Array of threshold limits to trigger each sensor.
long reading[] =   {0, 0, 0, 0, 0, 0, 0, 0}; //!< Current reading of each sensor.

Adafruit_VCNL4010 vcnl; //!< Object for the VNCL sensor.

//======================Variables for sleep==============================
unsigned long lastPressed = 0; //!< Time in ms since boot that a sensor was last pressed. Used to determine when to enter sleep mode after inactivity.

/*! Initialise the GPIO pins. This should be run AFTER initialising the display so the MISO pin can be detached from the pin matrix and reused. */
void initGPIO() {
  pinMode(BTNAPIN, INPUT);
  pinMode(BTNBPIN, INPUT);
  pinMode(INTERRUPTPIN, INPUT);
  pinMode(BATTMONPIN, INPUT);

  pinMatrixInDetach(VSPIQ_OUT_IDX, false, false); //detatch pin 19 from the VSPI MISO.
  pinMode(LEDAVAILPIN, OUTPUT);
  pinMode(LEDBUSYPIN, OUTPUT);
  pinMode(LEDOKPIN, OUTPUT);
  pinMode(LEDERRPIN, OUTPUT);
}

/*! Set the VCOM. This isn't normally needed unless the ePaper is particularly bad. */
void setVCOM(unsigned char d) {
  digitalWrite(4, LOW);
  digitalWrite(15, LOW);
  SPI.transfer(0x2C); //Write VCOM register
  digitalWrite(15, HIGH);
  digitalWrite(4, HIGH);
  digitalWrite(15, LOW);
  SPI.transfer(d);
  digitalWrite(15, HIGH);
}

/*! Selects which i2c sub-bus on the mux for a specific sensor to connect to and checks it, retrying if it's not correct. (input 0...7) */
void tcaselect(uint8_t i) { 
  if (i > 7) return;
  do {
    if (DEBUG_READINGS == 1) Serial.println((String)"[DEBUG] Selecting bus " + i);
    Wire.beginTransmission(TCAADDR);
    Wire.write(1 << i);
    Wire.endTransmission();
  } while (!(tcaget() == i));
}

/*! Check the current i2c sub-bus for a specific sensor. Output 0...7 */
int tcaget() { 
  Wire.requestFrom(TCAADDR, 1);
  byte c = Wire.read();
  for (int i = 0; i <= 7; i++) {
    if (c == 0x01) return i;
    c = c >> 1;
  }
}

/*! Attempt to initialise connected VCNL's one by one */
void detectVCNLs() {
  Serial.println("[INFO] Autodetecting sensors....");
  //addToLog("Autodetecting sensors....");
  for (int bus = 0; bus <= 7; bus++) {
    tcaselect(bus);
    int trynum = 1;
    while (! vcnl.begin() && trynum < TRIES) {
      if (DEBUG_READINGS == 1) Serial.println((String)"[DEBUG] Try " + trynum);
      trynum++;
      delay(100);
    }
    if (trynum < TRIES) {
      //found
      Serial.println((String)"[INFO] Found VCNL40xx on bus " + bus);
      doorbells++;
    }
    else {
      //not found
      Serial.println((String)"[INFO] No VCNL40xx on bus " + (String)bus + " terminating autodetection.");
      break;
    }
  }
  Serial.println("[INFO] Number of doorbells found: " + (String)doorbells);
  //addToLog((String)doorbells + " sensors found.");
  if (doorbells == 0) {
    errorMsg("Hardware error.\nNo VCNL sesnors found.\nContact support.");
  }
}

/*! Calibrate VCNL threshold by averaging N_THRES_SAMPLES samples and multiplying by thres */
void calibrateVCNLs() {
  for (int bus = 0; bus < doorbells; bus++) {
    tcaselect(bus);
    Serial.print("[INFO] Calibrating proximity threshold on bus " + (String)bus + " ");
    vcnl.setLEDcurrent(LEDCURR); //Set IR LED on to take measurement
    delay(10); //small delay to allow IR LED to stabilise
    for (int i = 0; i <= N_THRES_SAMPLES; i++) {
      int tmp = vcnl.readProximity();
      average[bus] = average[bus] + tmp;
      Serial.print((String)((100 / N_THRES_SAMPLES)*i) + "% ");
      delay(100);
    }
    vcnl.setLEDcurrent(0); //Set IR LED off
    average[bus] = average[bus] / N_THRES_SAMPLES;
    threshold[bus] = average[bus] * thres;
    Serial.println((String)"Average level was: " + average[bus] + " Threshold set to: " + threshold[bus]);
  }
  Serial.println("[INFO] Calibration done");
}

/*! Check if hardware buttons are pressed and run actions. */
void checkButtons() {
  if (digitalRead(BTNAPIN)) {
    lastPressed = millis(); //record the button was pressed for sleep mode
    Serial.println("[INFO] Button A Pressed");
    showInfo();
    while (digitalRead(BTNAPIN)) {}
  }
  if (digitalRead(BTNBPIN)) {
    lastPressed = millis(); //record the button was pressed for sleep mode
    Serial.println("[INFO] Button B Pressed");
    while (digitalRead(BTNBPIN)) {}
  }
}
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

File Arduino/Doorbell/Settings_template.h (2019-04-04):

/**
    \file Settings_template.h
    Contains user settings and presets that can be changed for build. Rename this file to Settings.h.
*/

//=========================Variables for wifi==========================
String ssid = ""; //!< WiFi SSID the device will connect to. Set from setup wizard.
String wifipsk = ""; //!< WiFi pre-shared key (password) the device will connect with. Set from setup wizard.
String EAP_IDENTITY = ""; //!< WPA2-ENTERPRISE (eduroam) email address. Set from setup wizard.
String EAP_PASSWORD = ""; //!< WPA2-ENTERPRISE (eduroam) password. Set from setup wizard.
String www_username = "admin"; //!< Defualt username for web config interface. Set from web config interface.
String www_password = "esp32"; //!< Defualt password for web config interface. Set from web config interface.

//===============Variables for doorbell operation======================
String room = "T815"; //!< Name of room device is fixed to. Set from web config interface.
String lecturerNames[5] = { "Name1", "Name2", "Name3", "", ""}; //!< Array of lectureres names. Set from web config interface.
String lecturerIFTTkeys[5] = { "Key1", "Key2", "Key3", "", ""}; //!< Array of lecturer IFTTT keys. Set from web config interface.
String lecturerStatus[5] = { "Available", "Away", "Busy", "", ""}; //!< Array of lecturer status. Set from web config interface.
float thres = 2; //!< Threshold for sensor.
bool busyNotif = false; //!< Notify lecturer anyway if they are busy?
bool powerSave = false; //!< Enter power saving mode after inactivity?
int sleepDelay = 15; //!< Period of inactivity in mins before entering power save mode.

//======================Definitions for hardware=======================
#define BTNAPIN 34 //!< GPIO pin number for A button.
#define BTNBPIN 35 //!< GPIO pin number for B button.
#define INTERRUPTPIN 32 //!< GPIO pin number for VCNL interrupt summary.
#define LEDAVAILPIN 19 //!< GPIO pin number for Available LED.
#define LEDBUSYPIN 17 //!< GPIO pin number for Busy LED.
#define LEDOKPIN 2 //!< GPIO pin number for OK LED.
#define LEDERRPIN 13 //!< GPIO pin number for Error LED.
#define BATTMONPIN 33 //!< GPIO pin number for battery voltage divider.
#define INTERRUPTPINMASK 0xC00000000 //!< Bit mask for button interrupt. Binary string of selected GPIO pins with GPIO0 being LSB, converted to hex. 0xC00000000 selects 34, 35.

//==========================Definitions for VCNL=======================
#define TCAADDR 0x70 //!< Default address of the multiplexer 0X70.
#define LEDCURR 10 //!< Current in IR LED, 10=100mA.
#define TRIES 3 //!< Number of tries to initialise each VCNL.
#define N_THRES_SAMPLES 10 //!< Number of samples to take when setting proximity threshold.
#define SCAN_INTERVAL 250 //!< Interval in ms between scans of all sensors.
#define DEBUG_READINGS 0 //!< Stream proximity readings to serial port 1/0.

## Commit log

2019-02-10 Commit of V1 PCB files
    [Daughterboard.brd, Daughterboard.sch, Daughterboard.skp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]
2019-02-10 First commit of code
    Settings currently stored locally.
2019-02-14 Schematic titled and tidied
    [Doorbell.sch]
2019-03-03 v0.2: Major tidy, added config file and web portals
    Code tidied into functions, grouped and put in seperate files for easier readability.
    Redundant code removed.
    Config file stored on SPI flash filesystem.
    Wifi setup wizard added.
    Config web portal added.
    Todo: WPA2-Enterprise
    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
2019-03-15 Fixed eduroam
    Fixed some GPIO mapping.
    Added status to web config page.
    Fixed eduroam support.
    [Config.ino, Doorbell.ino, GUI.ino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]
2019-03-18 WiFi connection attempts, GUI, Batt %.
    Makes 3 wifi connection attempts before falling back to config mode.
    Improvements to GUI.
    Fixed battery percentage.
    [Doorbell.ino, GUI.ino, Hardware.ino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]
2019-04-03 v1.0
    Major release. Everything is complete and working.
    Power saving implemented.
2019-04-15 PCB rev2 uploaded
    [Daughterboard.sch, Doorbell.brd, Doorbell.sch]

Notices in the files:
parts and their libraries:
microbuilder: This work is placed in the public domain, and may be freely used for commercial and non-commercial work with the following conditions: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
